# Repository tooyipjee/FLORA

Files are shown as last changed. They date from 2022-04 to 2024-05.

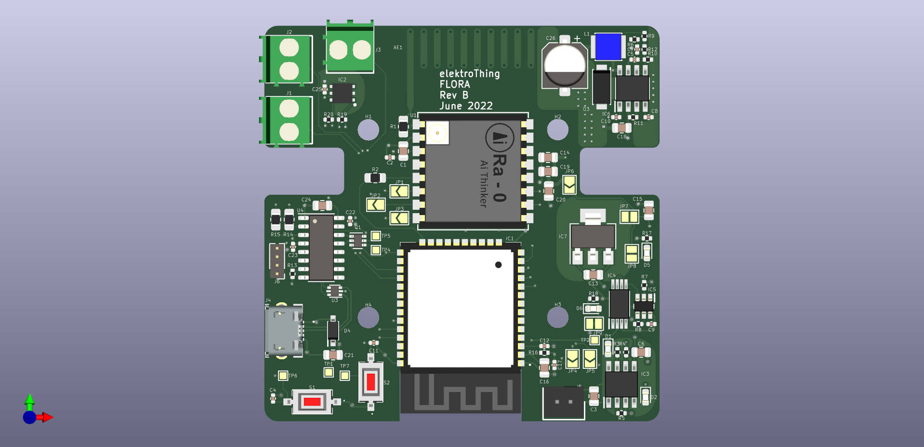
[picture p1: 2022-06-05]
images/flora.png

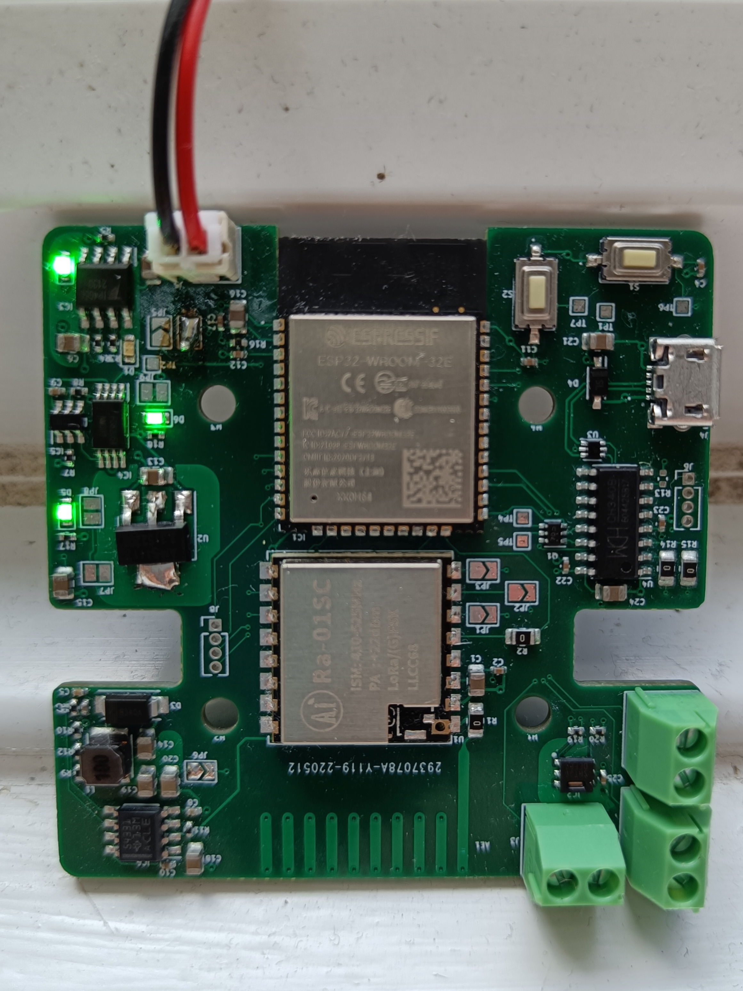
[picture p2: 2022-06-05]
images/IMG20220602151857.jpg

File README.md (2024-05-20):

FLORA: The Smart Garden Weather Station and Soil Moisture Monitor

In 2022, Europe faced its worst drought in over four decades. This marked a significant turning point for sustainable gardening practices across the continent. Amidst this crisis, there is an emerging solution that empowers communities to be more resilient and adaptive to extreme climates: FLORA - A Smart Garden Weather Station with Soil Moisture Monitoring.

The Need for Water-Efficient Practices in Europe's Gardens, Allotments, and Small Farms

The current climate crisis has made it imperative to rethink our approach towards water management and conservation. With the recent drought conditions across Europe, there is an urgent need to implement sustainable practices that can ensure a reliable food supply while conserving precious resources. The project at hand seeks to address this by creating smarter gardens and farms that are efficient in their use of water, thereby mitigating the risks associated with climate change-induced adversities.

Introducing FLORA: A Proof of Concept for Sustainable Gardening

FLORA is an innovative prototyping platform designed to enhance garden and farm productivity while promoting water conservation and sustainability. Built around a low-cost ESP32 SoC, it supports WiFi, BLE, and LoRa connectivity for efficient communication with other smart devices on the same network frequency band up to 3 km away.
e

The platform includes an ambient sensor and various inputs for integrating soil moisture sensors, providing a comprehensive view of environmental factors that influence plant growth. The goal is not just about making gardens more efficient; it's also about bringing communities back in control of their food production systems by making gardening processes rewarding and as effortless as possible.

What Makes FLORA Unique?

Long Range Communication: With the LoRa module, FLORA offers long-range communication up to approximately 2 miles/3 km. This feature is particularly beneficial for expansive gardens or allotments that require monitoring over larger areas without compromising on connectivity.

Soil Moisture Sensor Integration: The companion soil moisture sensor, based on capacitive sensing technology and insulated to prevent corrosion, provides real-time data about the water content in the top layer of the soil. This information is essential for optimizing irrigation practices and avoiding unnecessary water wastage.

Solar Power: FLORA runs on a solar panel powered by coin cell batteries, ensuring it operates sustainably without relying on conventional energy sources.

Vinduino Project Inspiration

The inspiration behind the design of FLORA comes from Reinier van der Lee's project, Vinduino, which showcases how simple electronics sensors can significantly reduce water usage in agriculture by up to 25%. The underlying principles and technologies have been adapted for use in gardening applications.

Building on Plant-Bot Project Experience

Reinier's experience with the Plant-Bot project laid a solid foundation for designing FLORA, allowing it to evolve into an outdoor-focused system that caters specifically to multiple plants and gardens.

Key Features of FLORA:

Compatibility with WiFi, BLE, and LoRa connectivity for seamless communication

Temperature accuracy within 0.3°C and humidity accuracy up to 3% RH using the SHT20 sensor

Capable of integrating various soil moisture sensors with capacitive-based technology

Long-range communication capabilities, extending FLORA's coverage area significantly

Efficient energy consumption powered by a solar panel and coin cell battery system

User-friendly design that empowers gardeners to take control of their plant care processes

Versatility in customization and integration with other smart devices within the same network frequency band

Specification Details:

Microcontroller: ESP32-WROOM-32E

WiFi Support: 802.11b/g/n standard

Bluetooth Capabilities: BLE 4.2 version

Flash Memory: 8MB capacity for firmware storage and execution

Programming Interface: USB over UART (CP2102) for direct programming and control

Environment Sensor: Incorporates the SHT20 sensor to measure temperature and humidity accurately

Soil Moisture Measurement: Utilizes capacitive sensing technology for reliable soil moisture readings

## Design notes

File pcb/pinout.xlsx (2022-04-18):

GPIO | Function 1 | System 1 | Function 2 | System 2
0 | Strapping | MCU
2 | TXEN | LoRa
4
5 | nNSS | LoRa
12 | TDI | SWD
13 | TCK | SWD
14 | nRESET | LoRa | TMS | SWD
15 | TDO | SWD
16 | SDA | I2C
17 | SCL | I2C
18 | SCK | LoRa
19 | MISO | LoRa
21 | BUSY | LoRa
22 | RXED | LoRa
23 | MOSI | LoRa
25 | DIO1 | LoRa
26 | DIO2 | LoRa
27 | DIO3 | LoRa
32
33 | SOIL_1 | SOIL
34 | SOIL_2 | SOIL
35 | SOIL_3 | SOIL

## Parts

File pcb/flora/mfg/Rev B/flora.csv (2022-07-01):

Comment | Designator | Footprint | LCSC
Antenna | AE1 | RF_Antenna:Texas_SWRA416_868MHz_915MHz
Battery_Cell | BT1 | BatteryHolders:BS-24-B4AK014
10u | C1,C3,C6,C13,C14,C15,C21,C24 | Capacitor_SMD:C_0805_2012Metric | C15850
22u | C16,C18,C19,C20 | Capacitor_SMD:C_0805_2012Metric | C602037
100n | C2,C4,C9,C10,C11,C12,C17,C22,C23,C25 | Capacitor_SMD:C_0402_1005Metric | C307331
220uF_E_LV | C26 | Capacitor_SMD:CP_Elec_6.3x5.4 | C3345
4.7n | C5 | Capacitor_SMD:C_0402_1005Metric | C1538
8.2n | C7,C8 | Capacitor_SMD:C_0402_1005Metric | C107032
Green_0603 | D1,D2,D5,D6 | LED_SMD:LED_0603_1608Metric | C72043
B340A-13-F | D3 | DIOM5226X240N | C64982
1N5819HWQ-7-F | D4 | SOD3716X145N | C2905649
MountingHole | H1,H2,H3,H4 | personal:MountingHole_3.2mm_M3_Small
ESP32-WROOM-32E(8MB) | IC1 | ESP32WROOM32E8MB | C701342
SHT20 | IC2 | SON100P300X300X110-7N
TP4056X | IC3 | SOIC127P600X175-9N | C16581
FS8205A | IC4 | SOP65P640X120-8N | C16052
DW01+G | IC5 | SamacSys_Parts:SOT95P280X145-6N | C14213
TPS54331DR | IC6 | SOIC127P600X175-8N
AMS1117-3.3 | IC7 | Package_TO_SOT_SMD:SOT-223-3_TabPin2 | C6186
KF350-3.5-2P | J1,J2,J3 | KF350352P | C474892
10118193-0001LF | J4 | 101181930001LF
PH-2V | J5 | SHDR2W52P0X200_1X2_600X460X630P | C146082
Conn_01x04 | J6 | Connector_PinHeader_1.27mm:PinHeader_1x04_P1.27mm_Vertical
SB_NO | JP1,JP2,JP3,JP4,JP5,JP6 | Jumper:SolderJumper-2_P1.3mm_Open_TrianglePad1.0x1.5mm
SB_NC | JP7,JP8,JP9 | Jumper:SolderJumper-2_P1.3mm_Bridged_Pad1.0x1.5mm
10uH | L1 | SamacSys_Parts:INDPM4040X300N | C38117
MUN5214DW1T1G | Q1 | Package_TO_SOT_SMD:SOT-363_SC-70-6 | C94403
0 | R1,R2,R14,R15 | Resistor_SMD:R_0805_2012Metric_Pad1.20x1.40mm_HandSolder | C17477
3.3k | R10 | Resistor_SMD:R_0402_1005Metric | C25890
220 | R12 | Resistor_SMD:R_0402_1005Metric | C25091
DNF_0402 | R13 | Resistor_SMD:R_0402_1005Metric
10k | R5,R9,R11,R16,R19,R20 | Resistor_SMD:R_0402_1005Metric | C25744
2.2k | R3,R18 | Resistor_SMD:R_0402_1005Metric | C25879
1k | R4,R6,R7,R17 | Resistor_SMD:R_0402_1005Metric | C11702
100 | R8 | Resistor_SMD:R_0402_1005Metric | C25076
TS-1101-C-W | S1,S2 | TS1101CW | C318938
USB Test Point | TP3 | personal:USB_TestPoint
TestPoint_Alt | TP1,TP2,TP4,TP5,TP6,TP7 | TestPoint:TestPoint_Pad_1.0x1.0mm
Ai-Thinker-Ra-01H | U1 | RF_Module:Ai-Thinker-Ra-01-LoRa | C503593
USBLC6-2P6 | U3 | Package_TO_SOT_SMD:SOT-666 | C2827693
CH340C | U4 | Package_SO:SOIC-16_3.9x9.9mm_P1.27mm | C84681

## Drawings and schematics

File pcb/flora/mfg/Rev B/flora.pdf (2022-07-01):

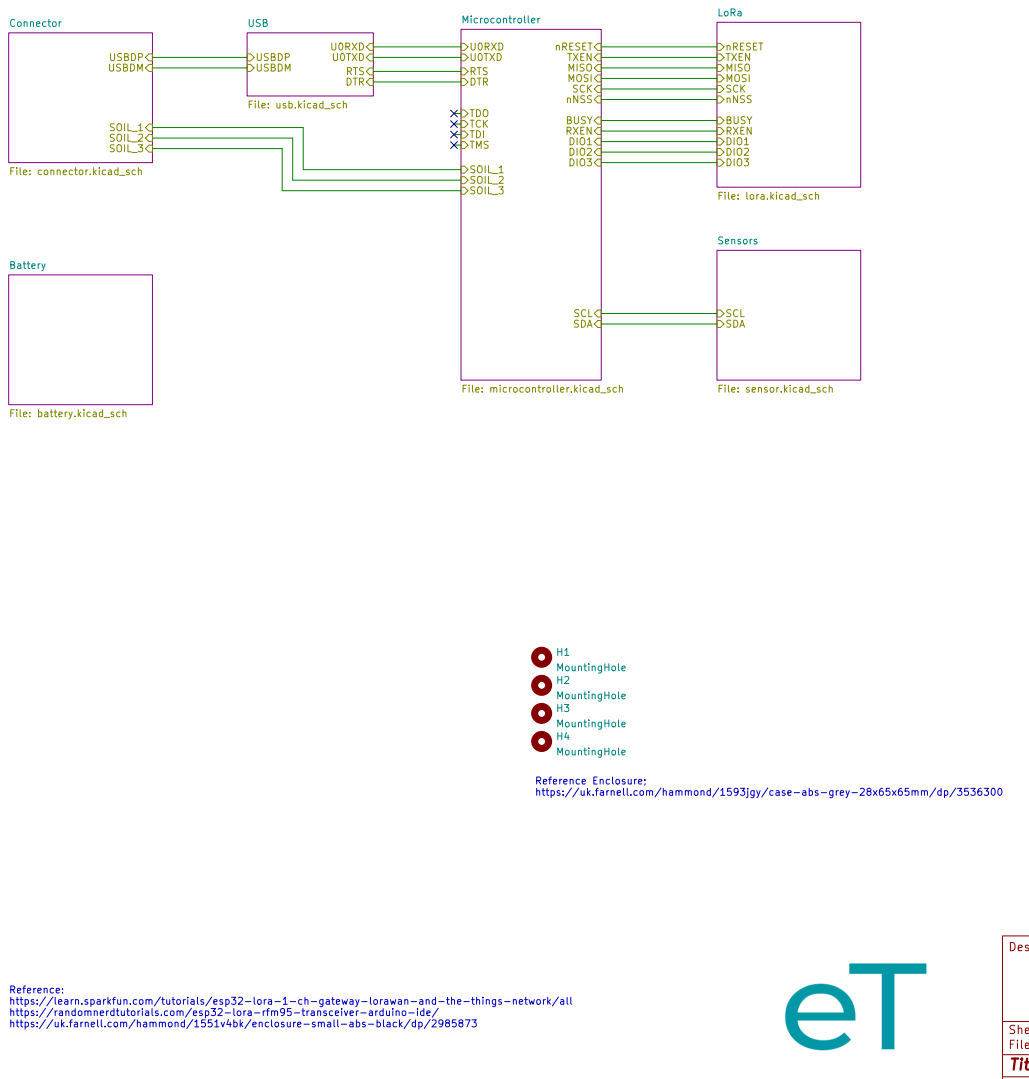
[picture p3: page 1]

LoRa File: lora.kicad_sch SDA
nRESET DIO2 DIO1 DIO3

DIO2 DIO3 DIO1 Microcontroller File: microcontroller.kicad_sch H4MountingHole H1MountingHole H2MountingHole H3MountingHole Reference: https://learn.sparkfun.com/tutorials/esp32-lora-1-ch-gateway-lorawan-and-the-things-network/all

RTS USB
TXEN MISO MOSI SCL SDA U0RXD
U0TXD
TDI TMS RTS DTR

SCL Sensors File: sensor.kicad_sch SOIL_3 SOIL_2 SOIL_1 USBDP USBDM

File: flora.kicad_sch Sheet: / Designed by elektroThing

https://randomnerdtutorials.com/esp32-lora-rfm95-transceiver-arduino-ide/

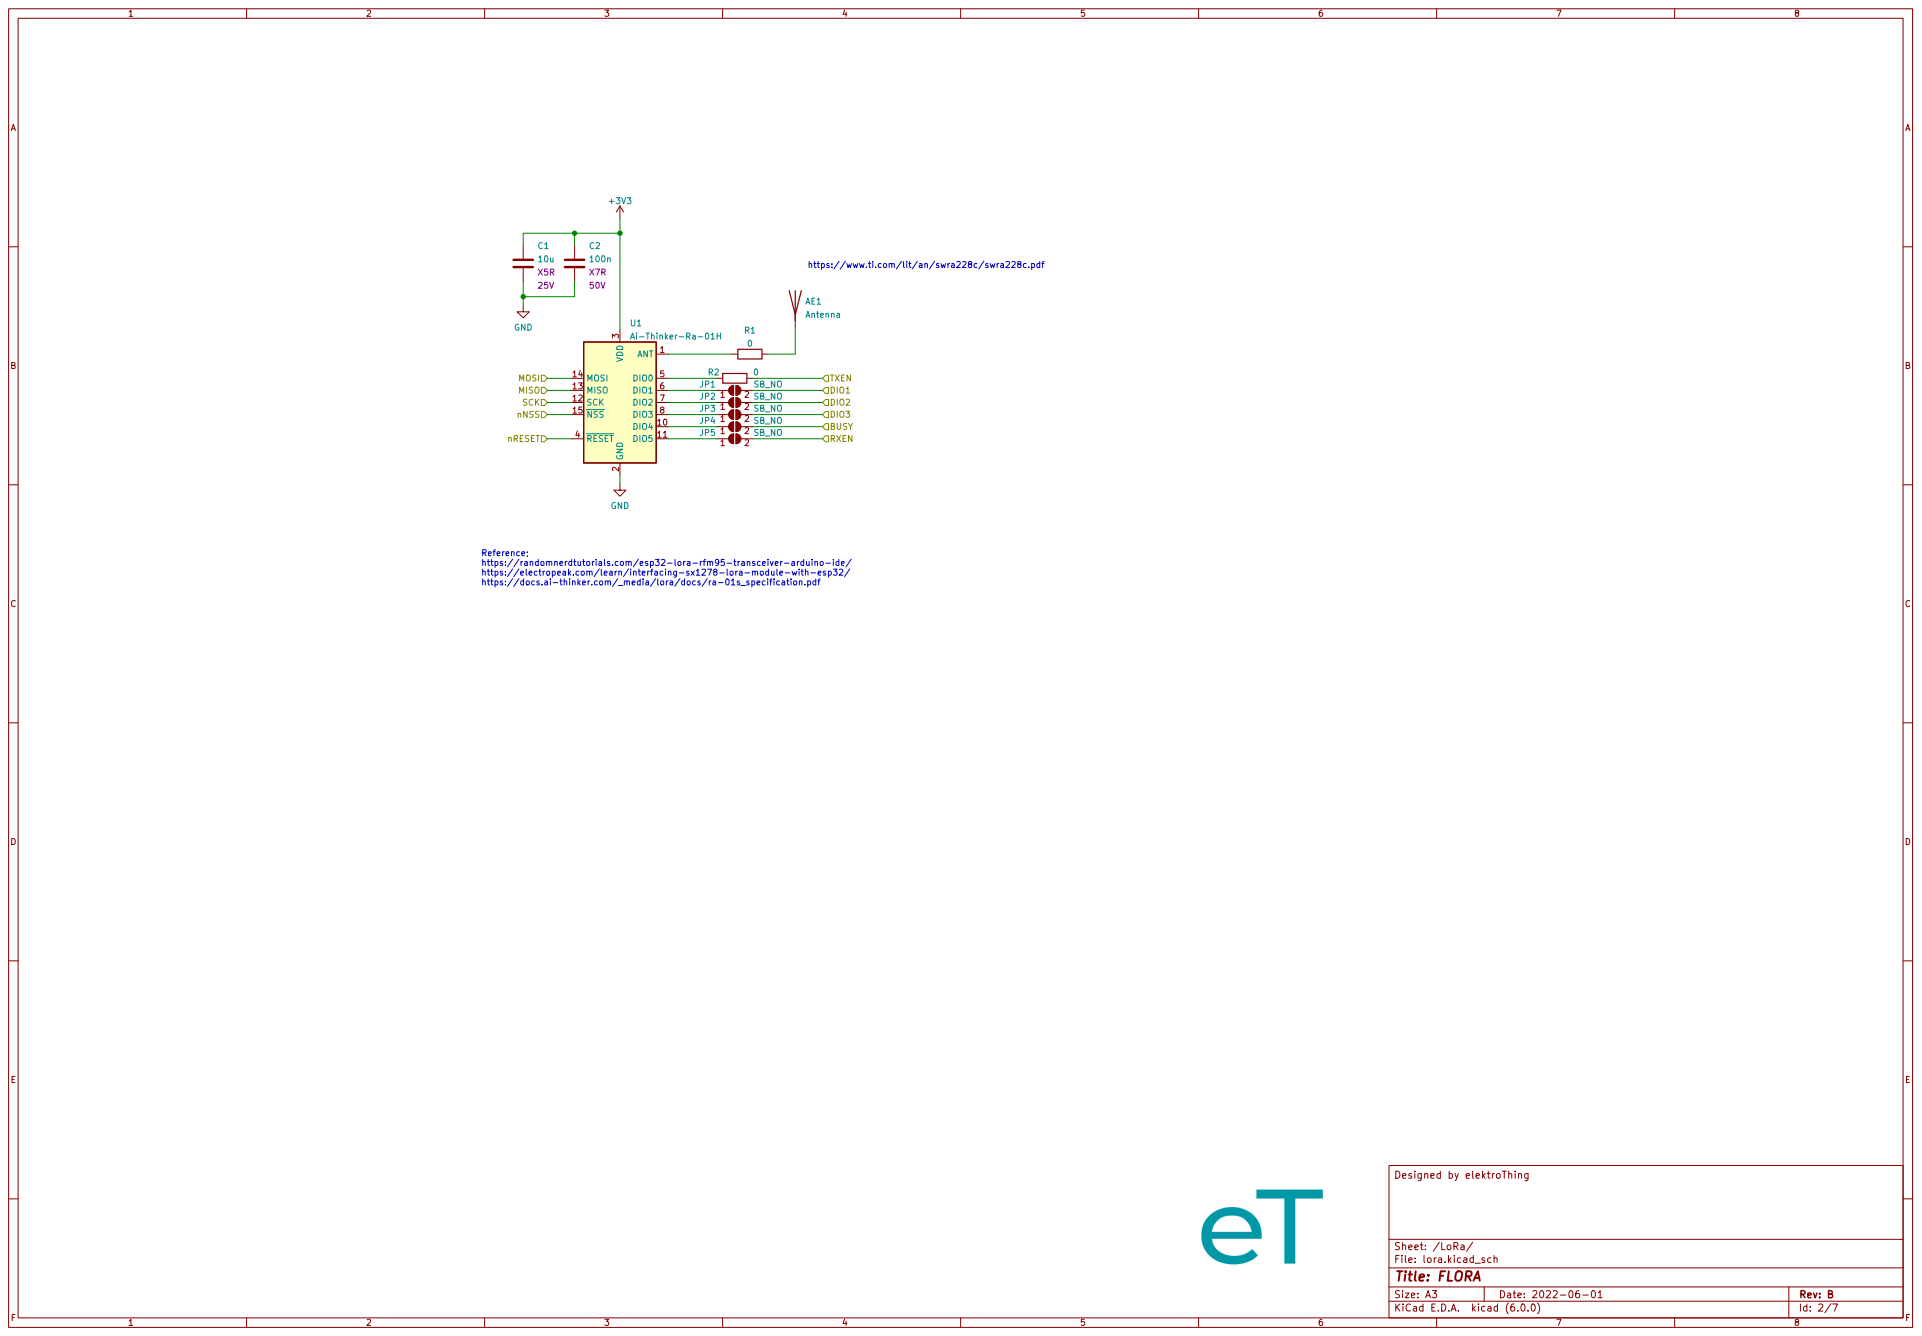
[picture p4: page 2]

https://www.ti.com/lit/an/swra228c/swra228c.pdf Reference; https://randomnerdtutorials.com/esp32-lora-rfm95-transceiver-arduino-ide/

3 ~{RESET} 4 DIO0 5 DIO1 6 DIO2 7 DIO3 8 U1Ai-Thinker-Ra-01H GND

https://electropeak.com/learn/interfacing-sx1278-lora-module-with-esp32/
https://docs.ai-thinker.com/_media/lora/docs/ra-01s_specification.pdf

File: lora.kicad_sch Sheet: /LoRa/ Designed by elektroThing

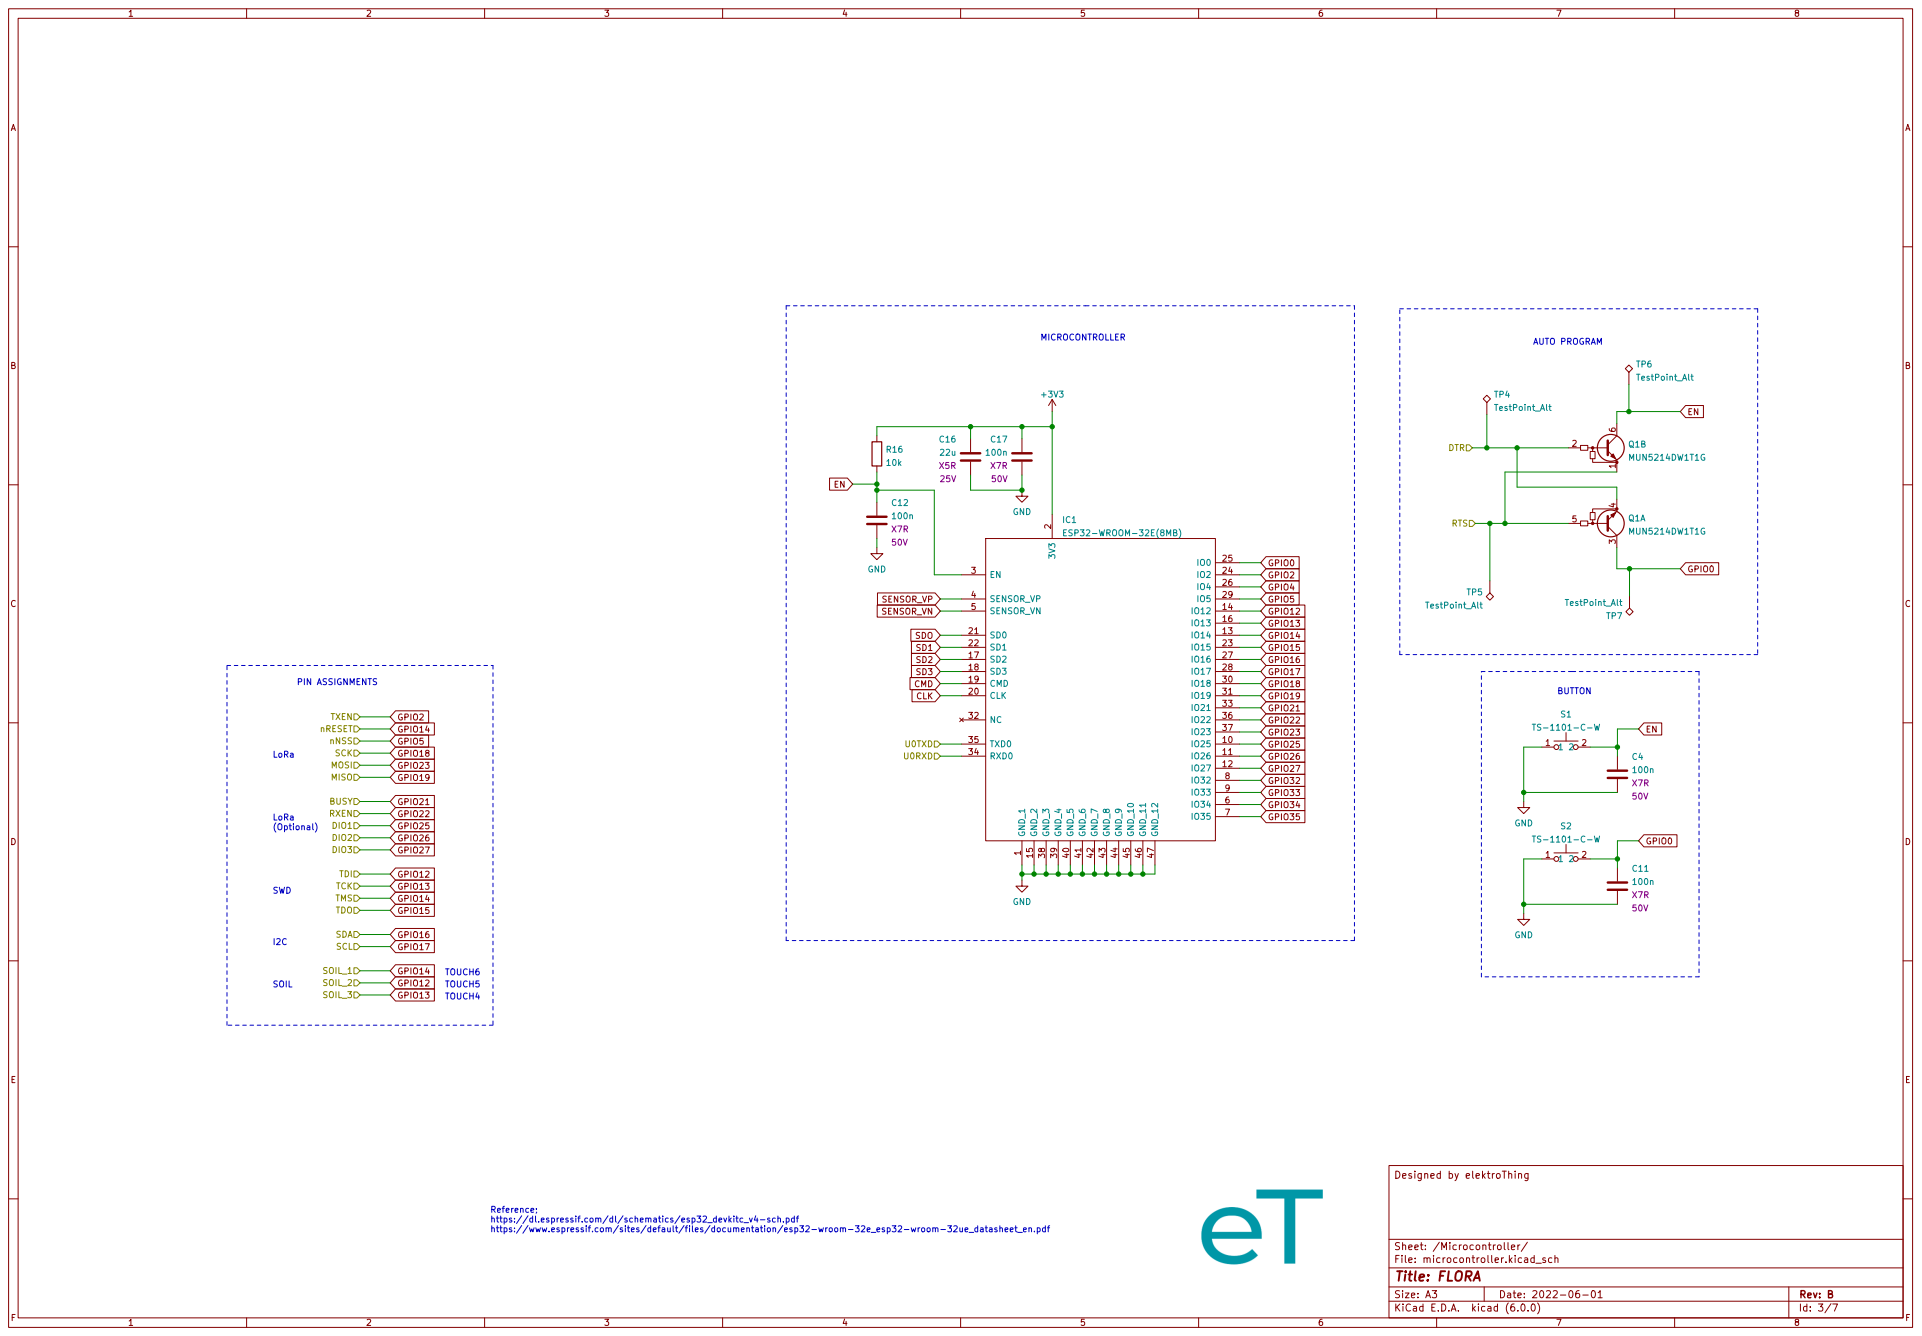
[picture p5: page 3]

File: microcontroller.kicad_sch Sheet: /Microcontroller/ Designed by elektroThing GND

https://www.espressif.com/sites/default/files/documentation/esp32-wroom-32e_esp32-wroom-32ue_datasheet_en.pdf SWD

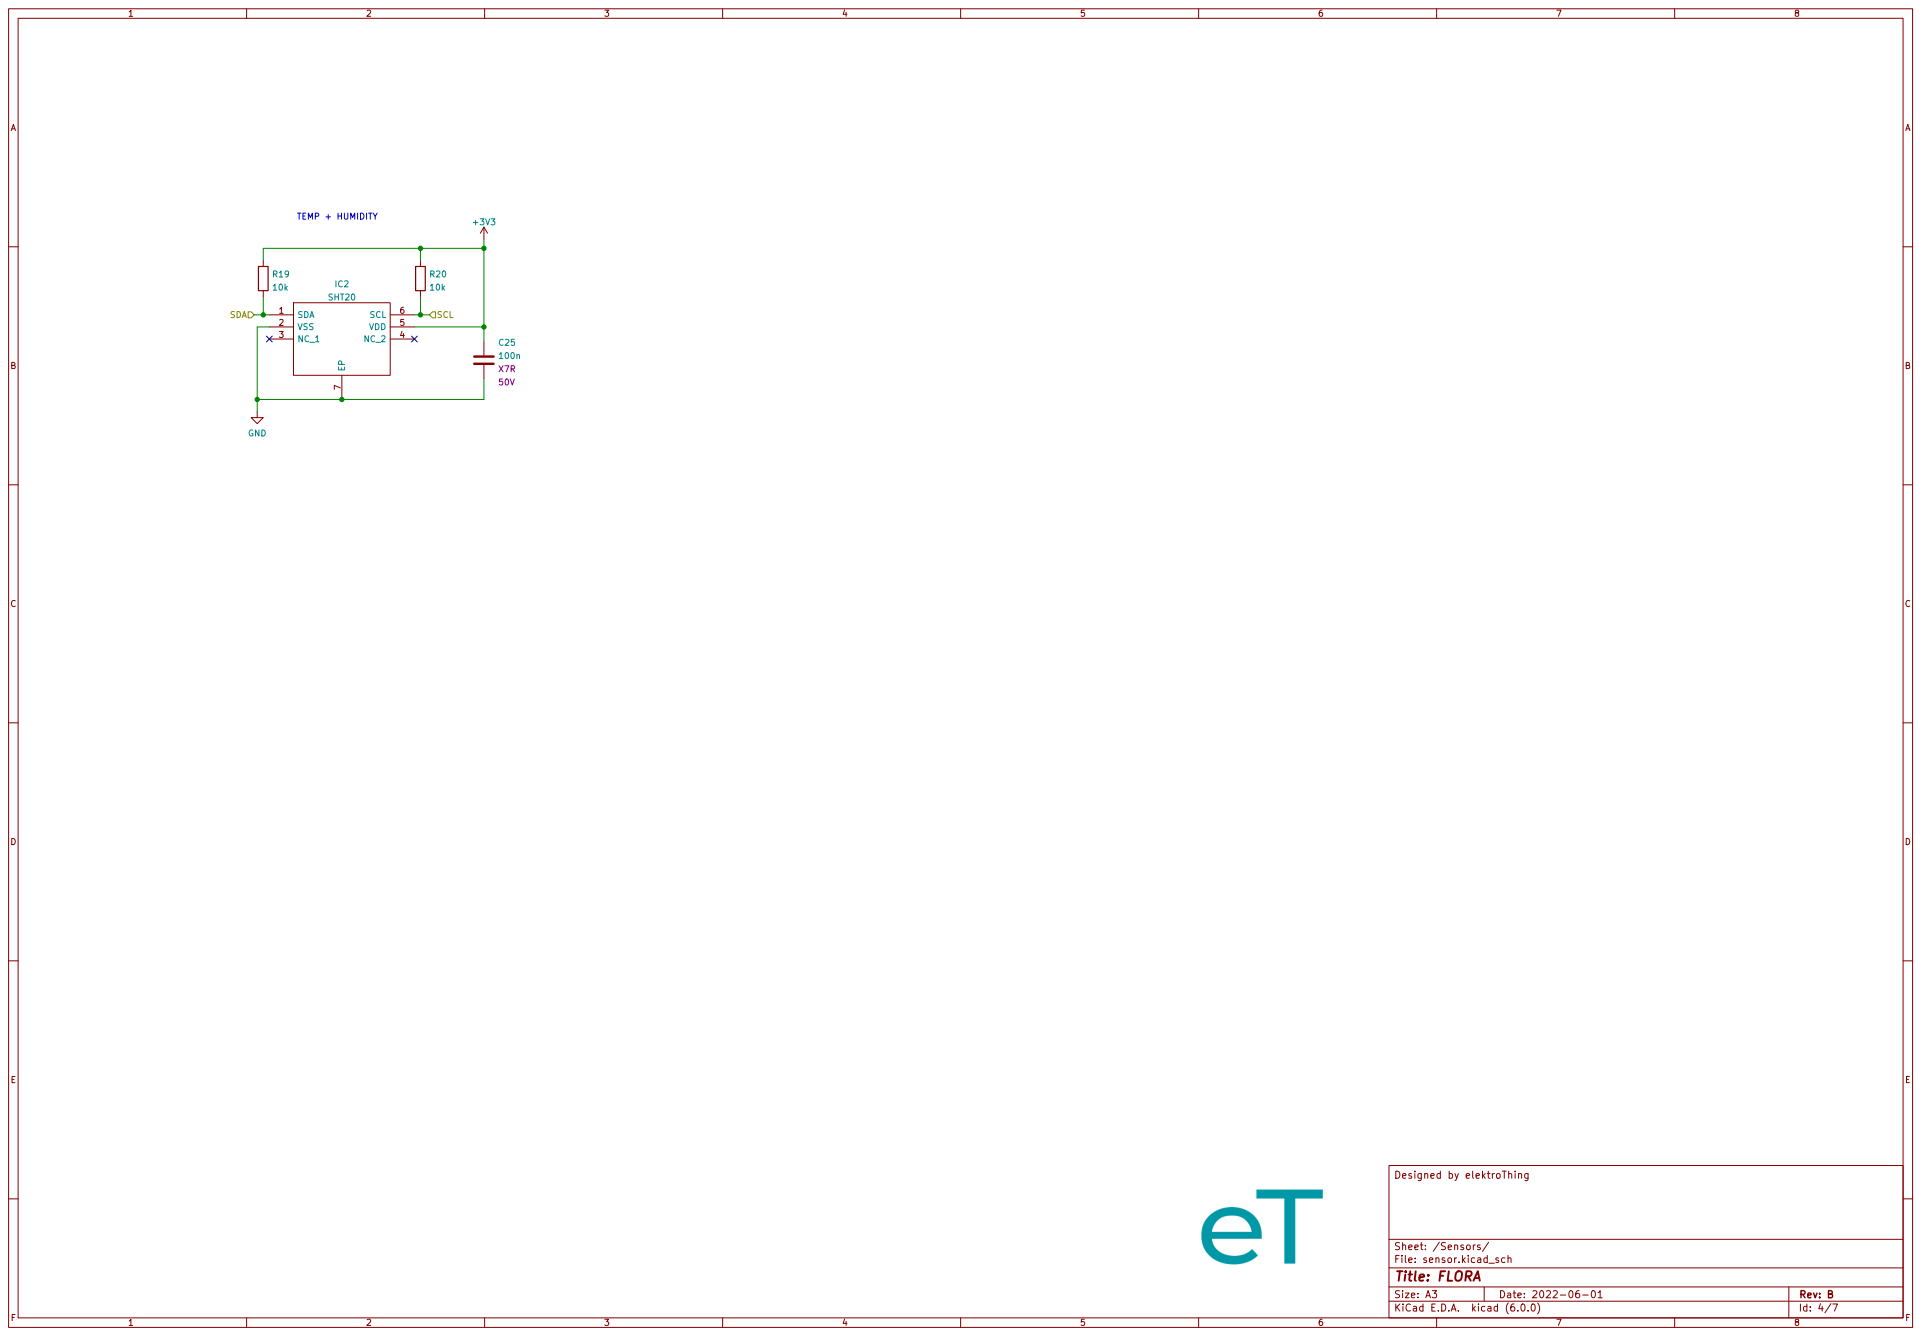
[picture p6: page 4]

File: sensor.kicad_sch Sheet: /Sensors/ Designed by elektroThing

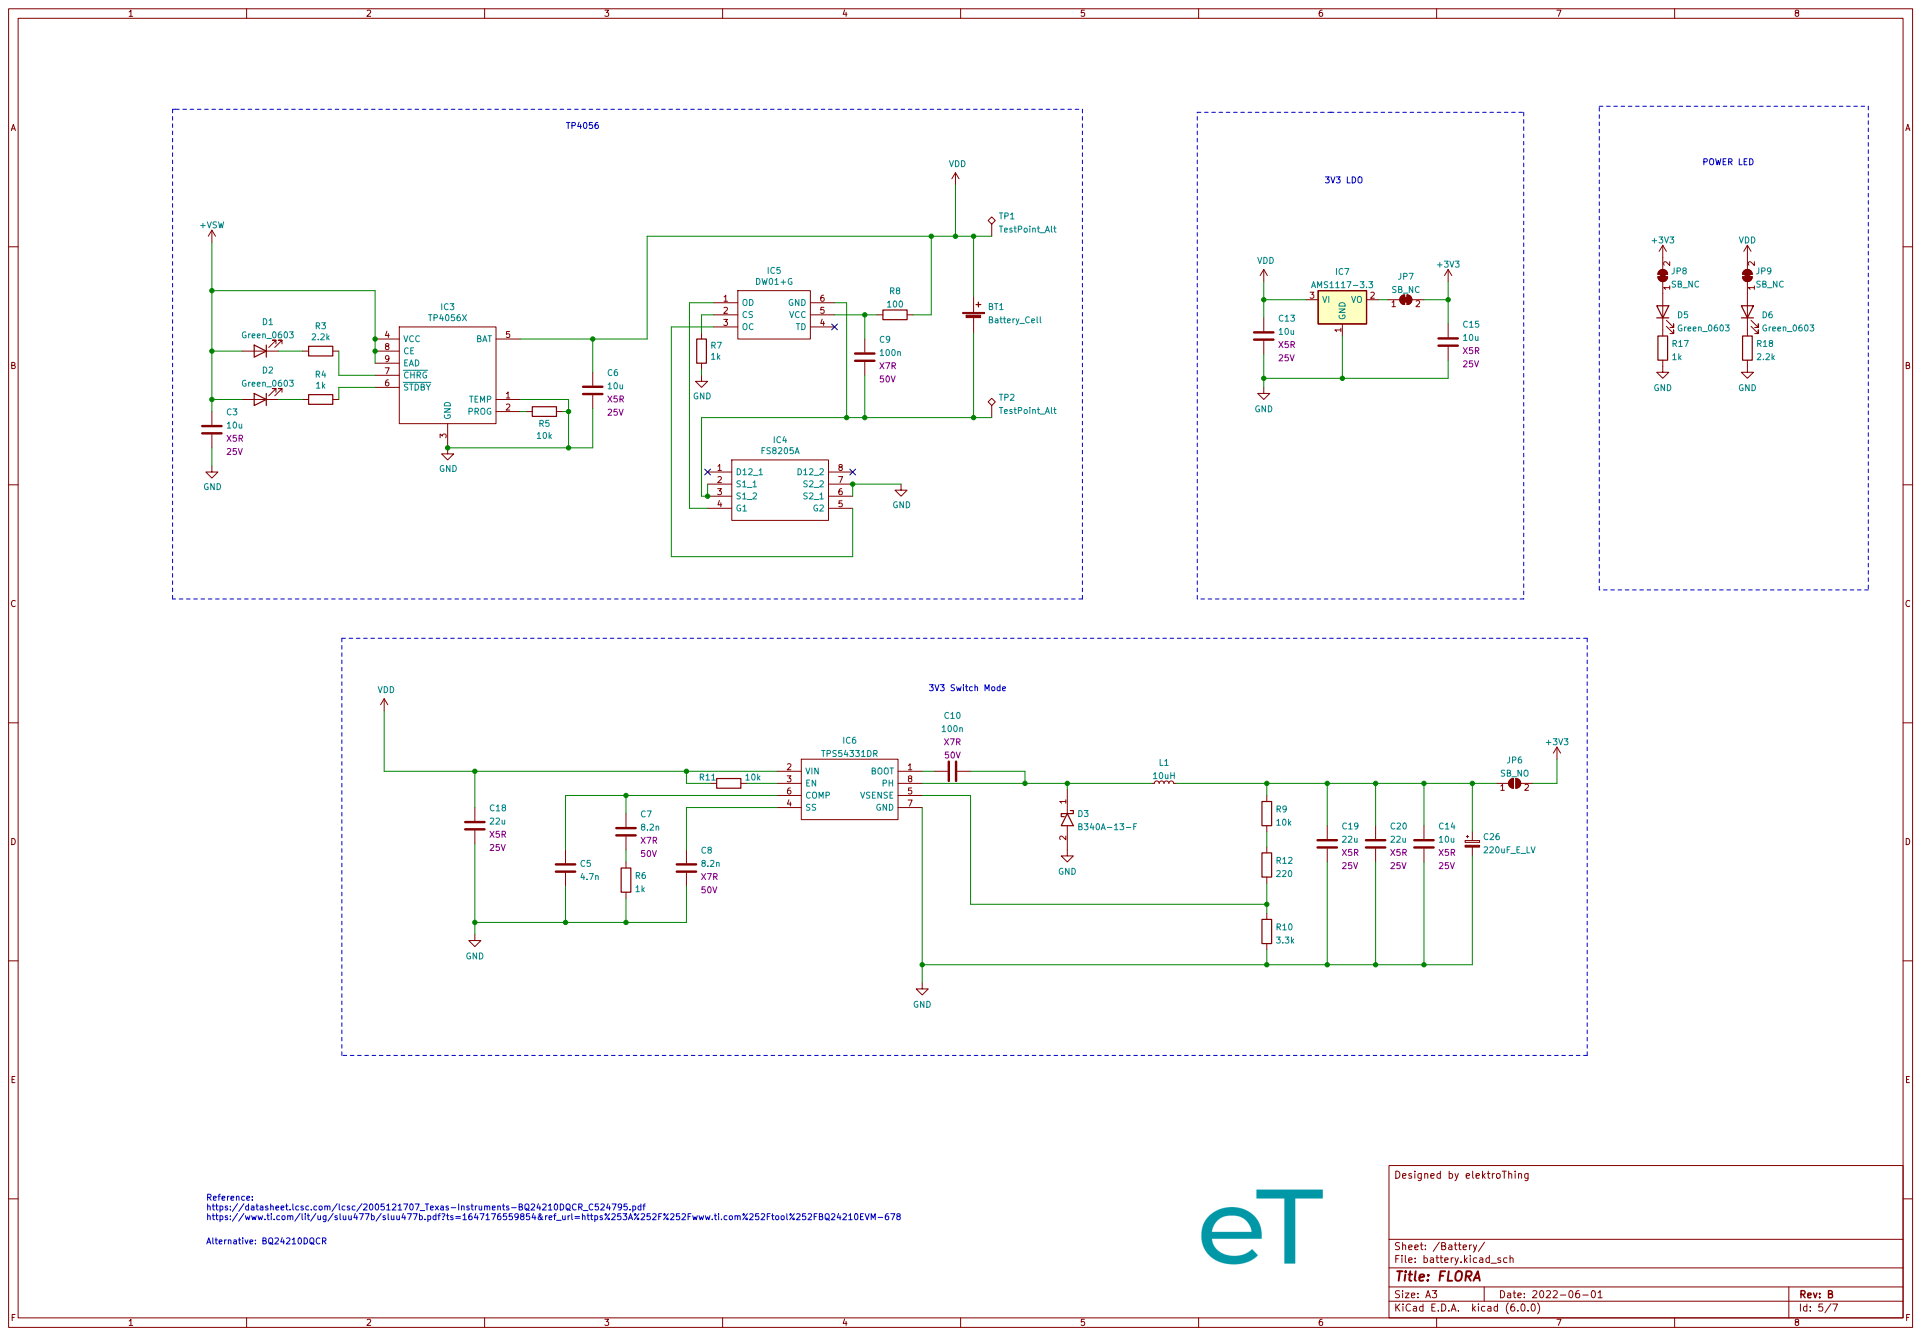
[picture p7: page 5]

3 VCC 4 BAT 5 ~{STDBY} 6 ~{CHRG} 7 CE 8 EAD 9

GND GND

3V3 Switch Mode Reference: https://datasheet.lcsc.com/lcsc/2005121707_Texas-Instruments-BQ24210DQCR_C524795.pdf

https://www.ti.com/lit/ug/sluu477b/sluu477b.pdf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 Alternative: BQ24210DQCR

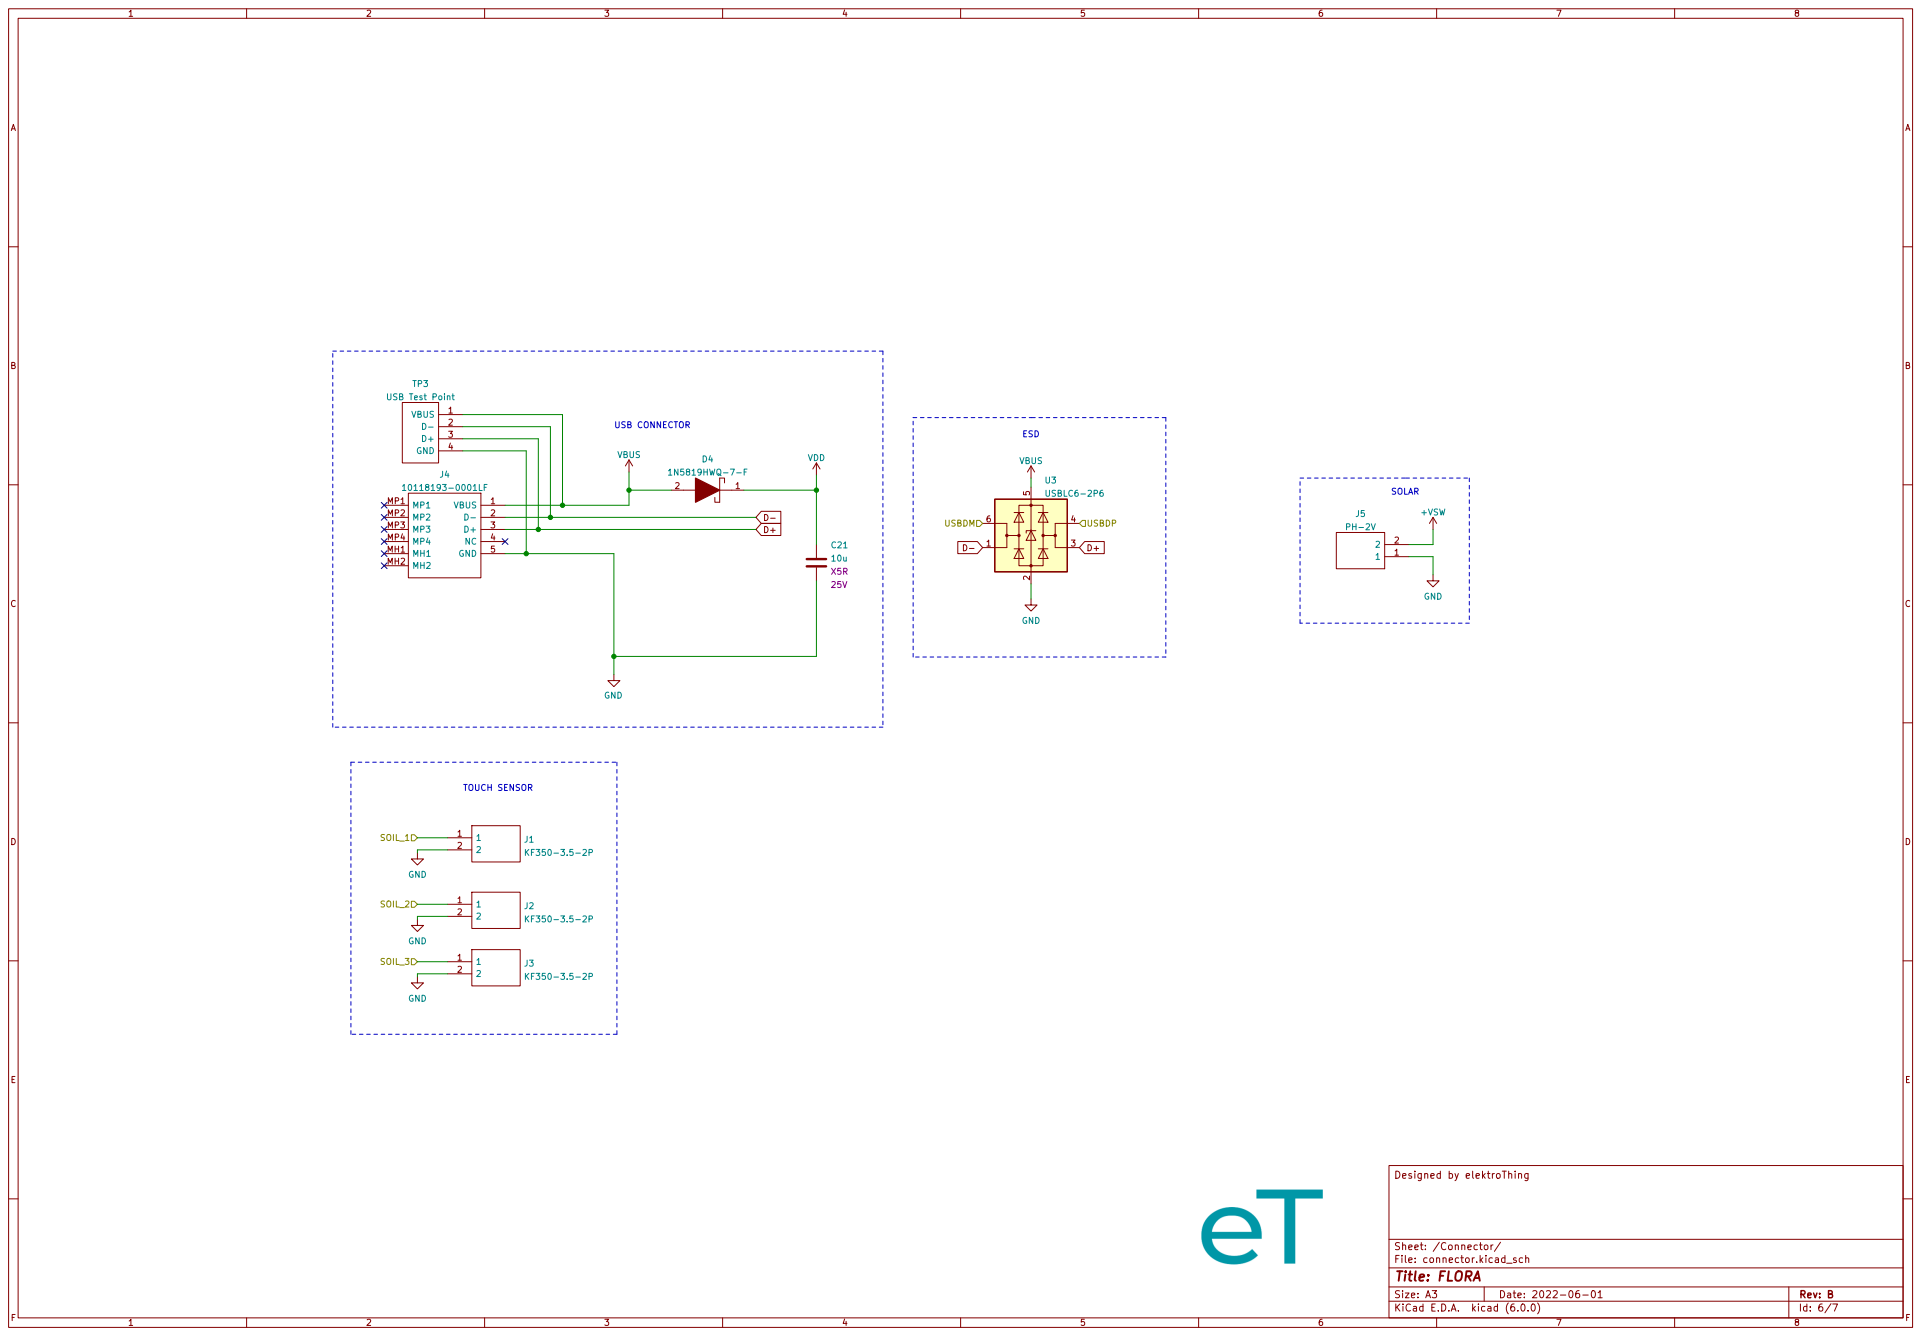
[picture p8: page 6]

File: connector.kicad_sch Sheet: /Connector/ Designed by elektroThing

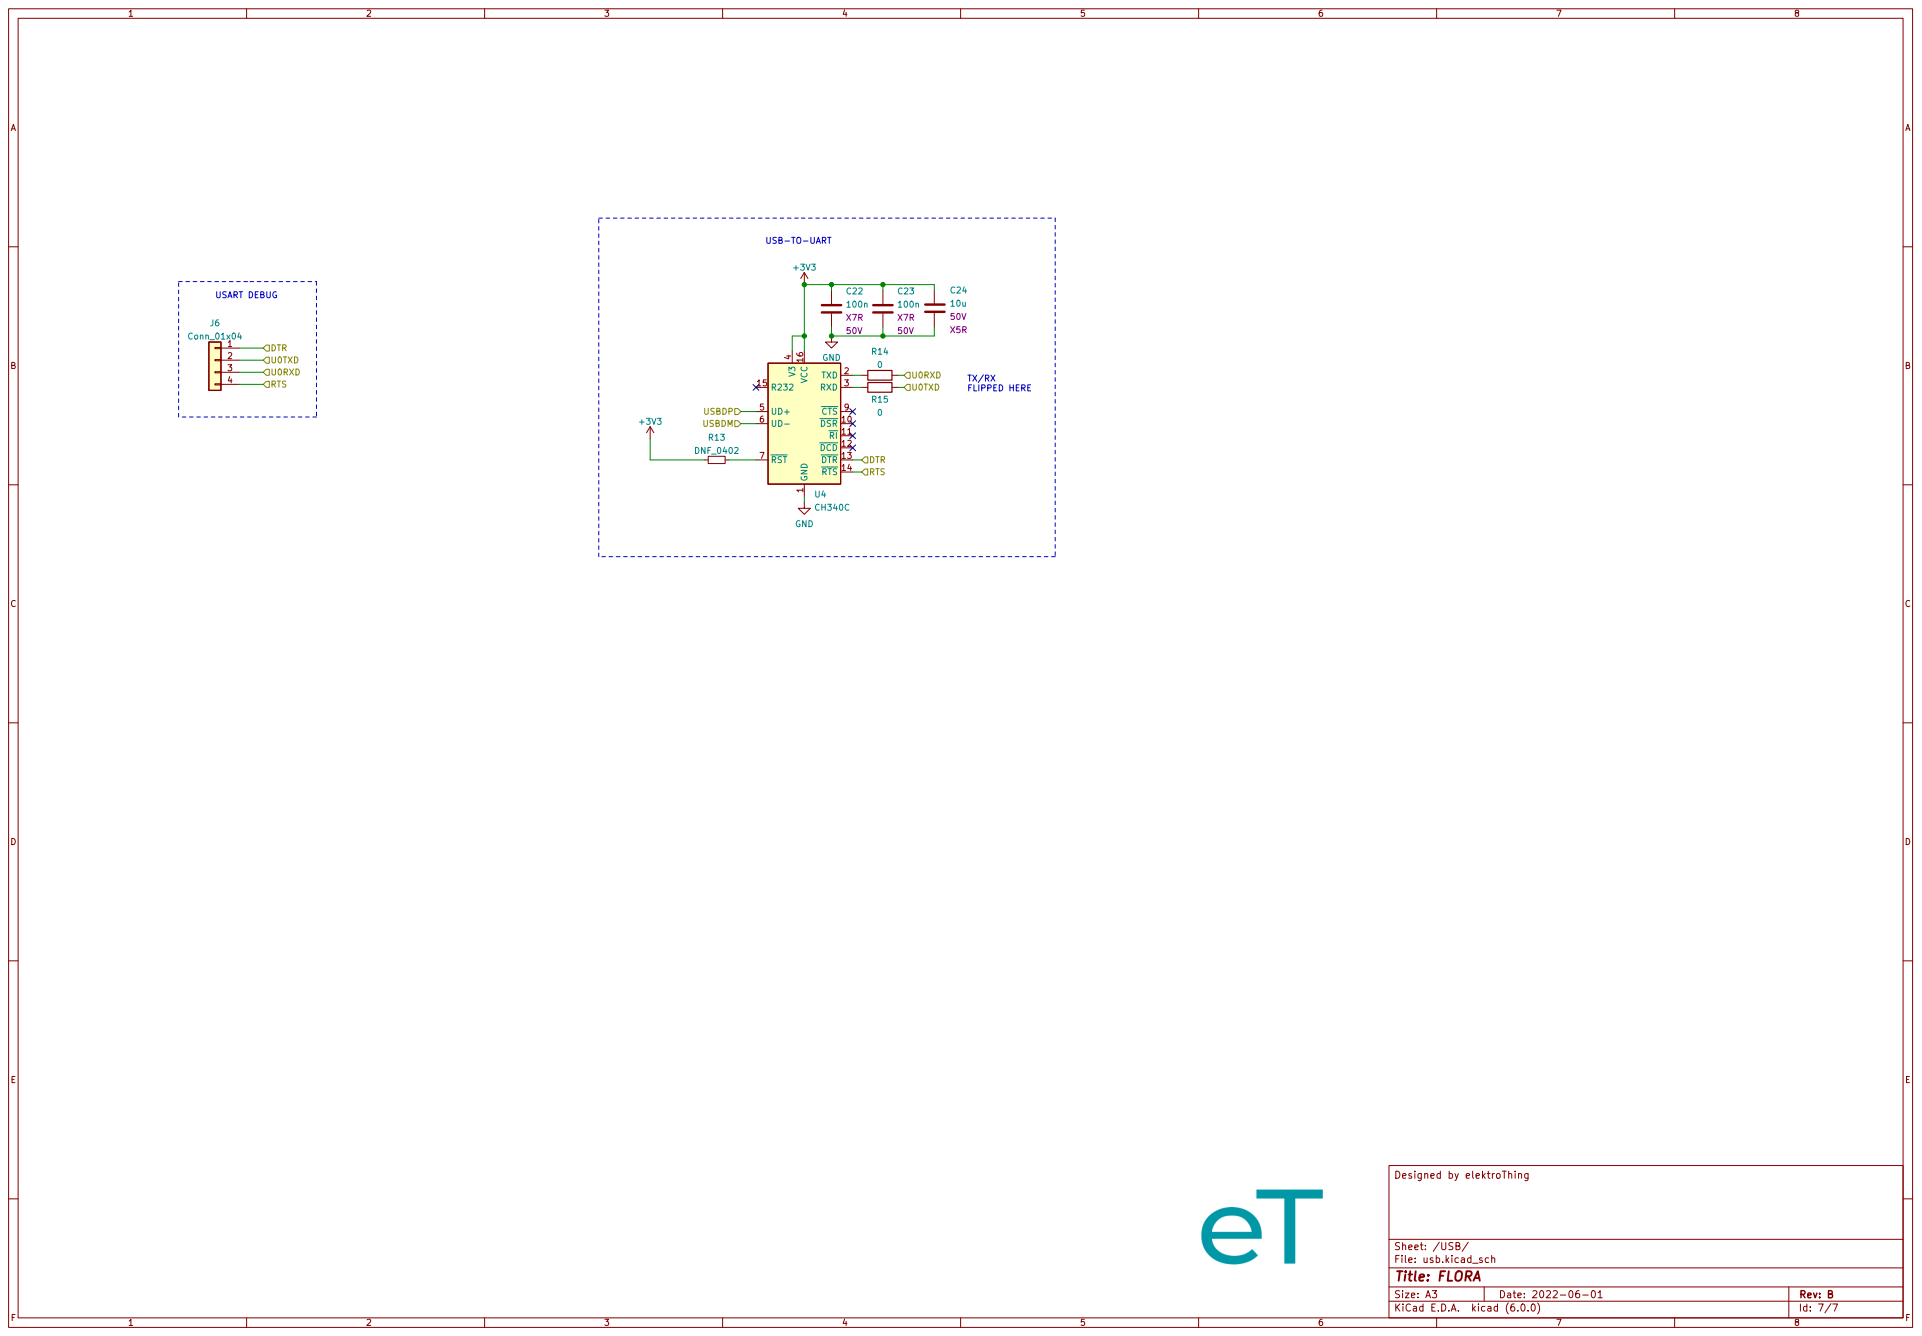
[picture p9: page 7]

USB-TO-UART USART DEBUG

1 ~{DSR}10 ~{RI}11 ~{DCD}12 ~{DTR}13 ~{RTS}14 R232 15 VCC 16 TXD 2 RXD 3 V3

4 UD+ 5 UD- 6 ~{RST} 7 ~{CTS} 9 U4CH340C

TX/RX FLIPPED HERE

File: usb.kicad_sch Sheet: /USB/ Designed by elektroThing

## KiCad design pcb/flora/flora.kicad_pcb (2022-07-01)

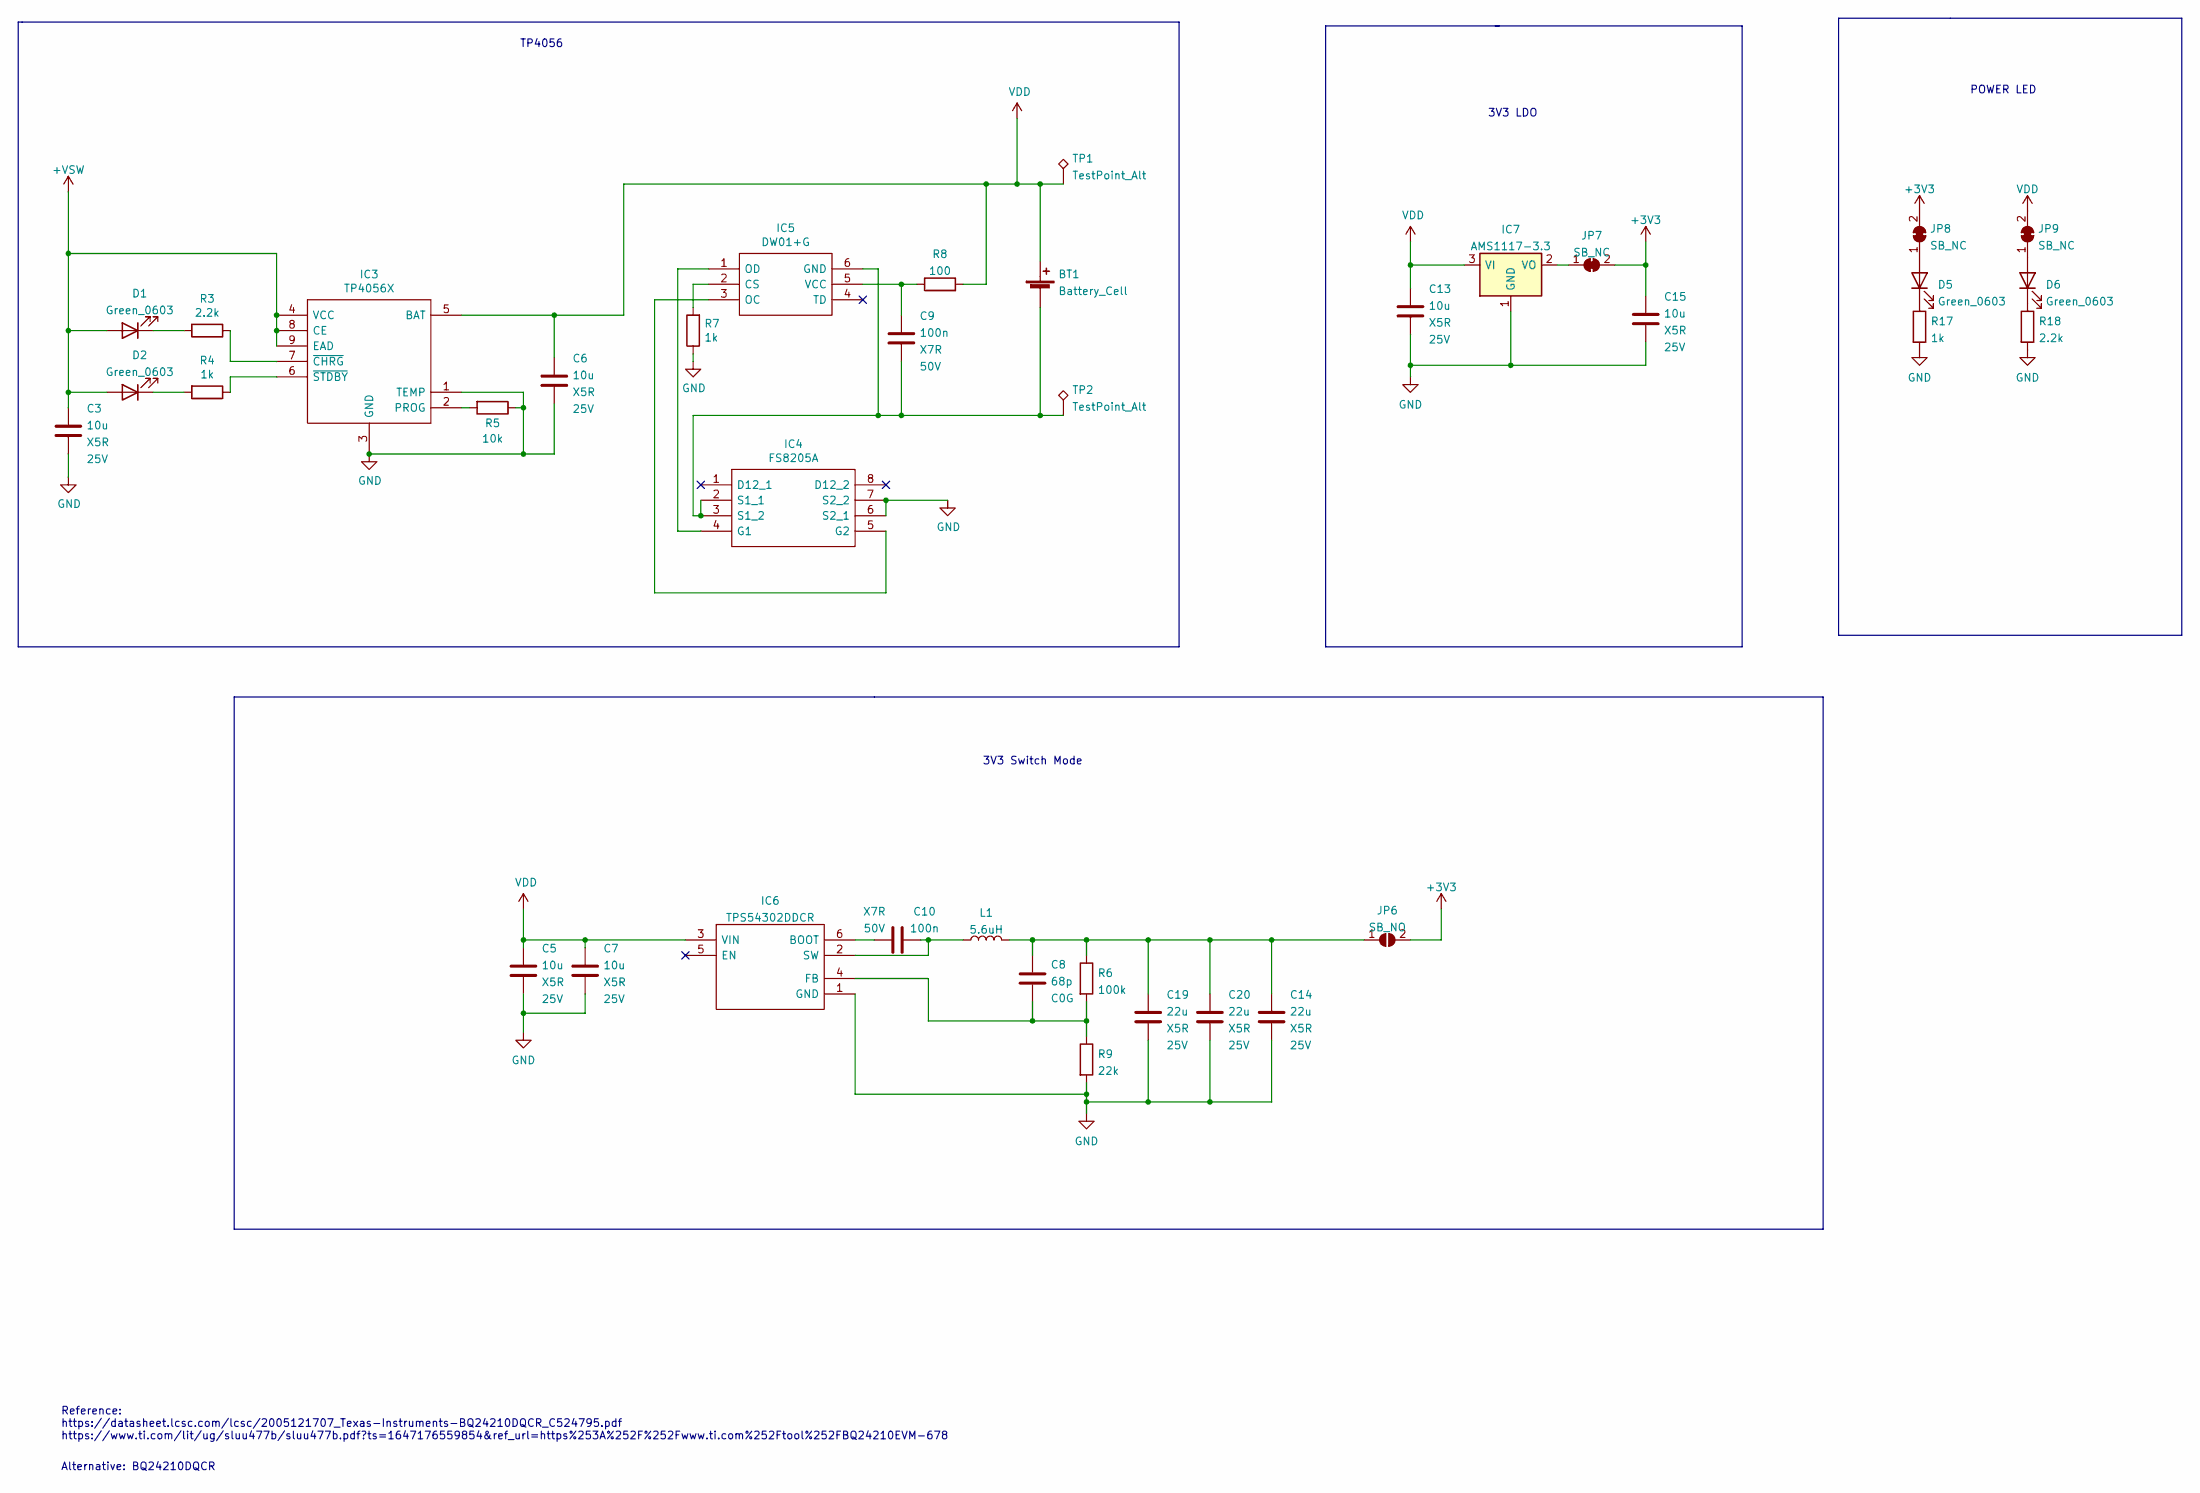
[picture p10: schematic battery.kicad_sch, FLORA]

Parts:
BT1: Battery_Cell; BS-24-B4AK014
C3, C5, C6, C7, C13, C15: 10u; C_0805_2012Metric; Voltage 25V; LCSC C15850
C8: 68p; C_0402_1005Metric; Rating 50V; LCSC C14441
C9, C10: 100n; C_0402_1005Metric; Voltage 50V; LCSC C307331
C14, C19, C20: 22u; C_0805_2012Metric; Voltage 25V; LCSC C602037
D1, D2, D5, D6: Green_0603; LED_0603_1608Metric; LCSC C72043
IC3: TP4056X; SOIC127P600X175-9N; Manufacturer_Part_Number TP4056X; LCSC C16581
IC4: FS8205A; SOP65P640X120-8N; Manufacturer_Part_Number FS8205A; LCSC C16052
IC5: DW01+G; SOT95P280X145-6N; Manufacturer_Part_Number DW01+G; LCSC C14213
IC6: TPS54302DDCR; SOT95P280X110-6N; Manufacturer_Part_Number TPS54302DDCR; Mouser Part Number 595-TPS54302DDCR
IC7: AMS1117-3.3; SOT-223-3_TabPin2; Manufacturer_Part_Number AMS1117-3.3; LCSC C6186
JP6: SB_NO; SolderJumper-2_P1.3mm_Open_TrianglePad1.0x1.5mm
JP7, JP8, JP9: SB_NC; SolderJumper-2_P1.3mm_Bridged_Pad1.0x1.5mm
L1: 5.6uH; INDPM4040X300N; LCSC C167783
R3, R18: 2.2k; R_0402_1005Metric; LCSC C25879
R4, R7, R17: 1k; R_0402_1005Metric; LCSC C11702
R5: 10k; R_0402_1005Metric; LCSC C25744
R6: 100k; R_0402_1005Metric; LCSC C25741
R8: 100; R_0402_1005Metric; LCSC C25076
R9: 22k; R_0402_1005Metric; LCSC C25768
TP1, TP2: TestPoint_Alt; TestPoint_Pad_1.0x1.0mm

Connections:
+3V3: C15.1, JP6.2 (B), JP7.2 (B), JP8.2 (B); also elsewhere on the board
+VSW: C3.1, D1.2 (A), D2.2 (A), IC3.4 (VCC), IC3.8 (CE), IC3.9 (EAD); also elsewhere on the board
GND: C3.2, C5.2, C6.2, C7.2, C13.2, C14.2, C15.2, C19.2, C20.2, IC3.1 (TEMP), IC3.3 (GND), IC4.6 (S2_1), IC4.7 (S2_2), IC6.1 (GND), IC7.1 (GND), R5.1, R7.1, R9.2, R17.2, R18.2; also elsewhere on the board
unnamed: BT1.2 (-), C9.2, IC4.2 (S1_1), IC4.3 (S1_2), IC5.6 (GND), TP2.1
unnamed: C8.2, IC6.4 (FB), R6.2, R9.1
unnamed: C9.1, IC5.5 (VCC), R8.1
unnamed: C10.1, IC6.6 (BOOT)
unnamed: C10.2, IC6.2 (SW), L1.1
unnamed: C8.1, C14.1, C19.1, C20.1, JP6.1 (A), L1.2, R6.1
unnamed: D1.1 (K), R3.2
unnamed: D2.1 (K), R4.2
unnamed: D5.1 (K), R17.1
unnamed: D5.2 (A), JP8.1 (A)
unnamed: D6.1 (K), R18.1
unnamed: D6.2 (A), JP9.1 (A)
unnamed: IC3.2 (PROG), R5.2
unnamed: IC3.6 (~STDBY), R4.1
unnamed: IC3.7 (~CHRG), R3.1
unnamed: IC4.4 (G1), IC5.1 (OD)
unnamed: IC4.5 (G2), IC5.3 (OC)
unnamed: IC5.2 (CS), R7.2
unnamed: IC7.2 (VO), JP7.1 (A)
VDD: BT1.1 (+), C5.1, C6.1, C7.1, C13.1, IC3.5 (BAT), IC6.3 (VIN), IC7.3 (VI), JP9.2 (B), R8.2, TP1.1; also elsewhere on the board

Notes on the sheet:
3V3 Switch Mode
Reference: https://datasheet.lcsc.com/lcsc/2005121707_Texas-Instruments-BQ24210DQCR_C524795.pdf https://www.ti.com/lit/ug/sluu477b/sluu477b.pdf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
POWER LED
TP4056
Alternative: BQ24210DQCR
3V3 LDO

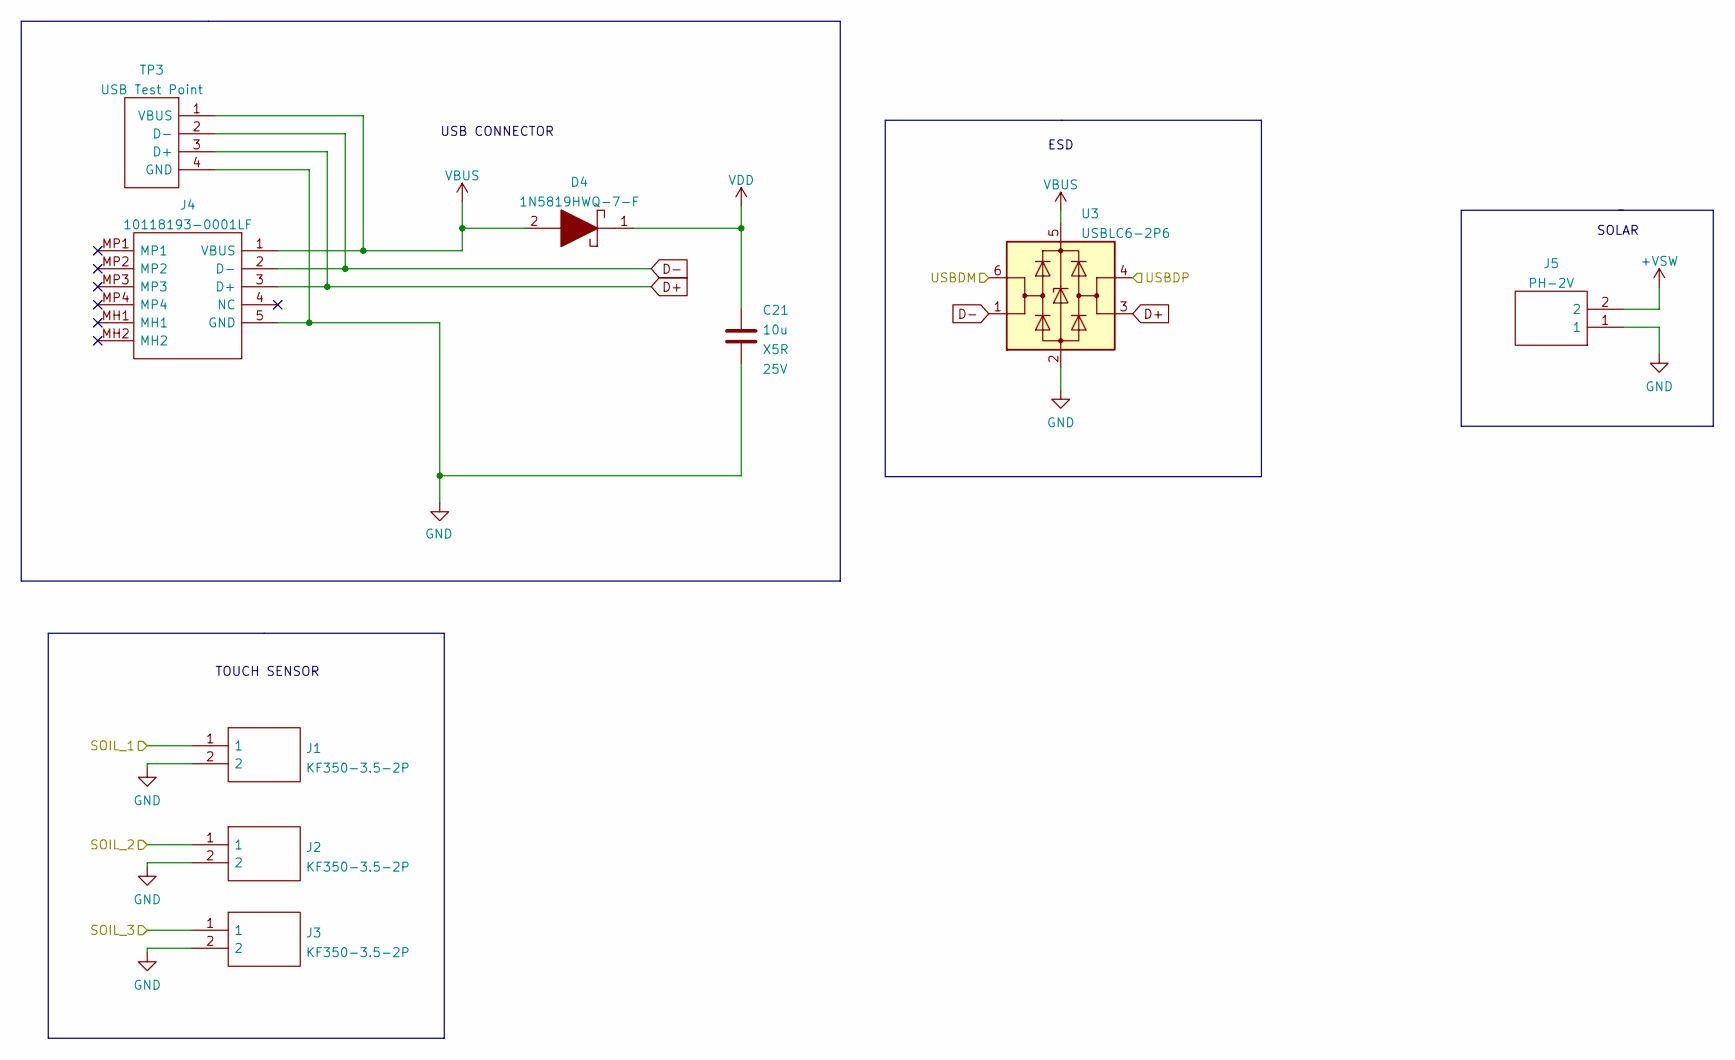
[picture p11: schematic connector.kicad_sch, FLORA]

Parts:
C21: 10u; C_0805_2012Metric; Voltage 25V; LCSC C15850
D4: 1N5819HWQ-7-F; SOD3716X145N; Manufacturer_Part_Number 1N5819HWQ-7-F; Mouser Part Number 621-1N5819HWQ-7-F
J1, J2, J3: KF350-3.5-2P; KF350352P; Manufacturer_Part_Number KF350-3.5-2P; LCSC C474892
J4: 10118193-0001LF; 101181930001LF; Manufacturer_Part_Number 10118193-0001LF; Mouser Part Number 649-10118193-0001LF
J5: PH-2V; SHDR2W52P0X200_1X2_600X460X630P; Manufacturer_Part_Number PH-2AK; LCSC C146082
TP3: USB Test Point; USB_TestPoint
U3: USBLC6-2P6; SOT-666; LCSC C2827693

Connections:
+VSW: J5.2; also elsewhere on the board
/Connector/USBDM: U3.6 (I/O1); also elsewhere on the board
/Connector/USBDP: U3.4 (I/O2); also elsewhere on the board
D+: J4.3 (D+), TP3.3 (D+), U3.3 (I/O2)
D-: J4.2 (D-), TP3.2 (D-), U3.1 (I/O1)
GND: C21.2, J1.2, J2.2, J3.2, J4.5 (GND), J5.1, TP3.4 (GND), U3.2 (GND); also elsewhere on the board
GPIO12: J2.1; also elsewhere on the board
GPIO13: J3.1; also elsewhere on the board
GPIO14: J1.1; also elsewhere on the board
VBUS: D4.2, J4.1 (VBUS), TP3.1 (VBUS), U3.5 (VBUS)
VDD: C21.1, D4.1; also elsewhere on the board

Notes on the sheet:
SOLAR
USB CONNECTOR
ESD
TOUCH SENSOR

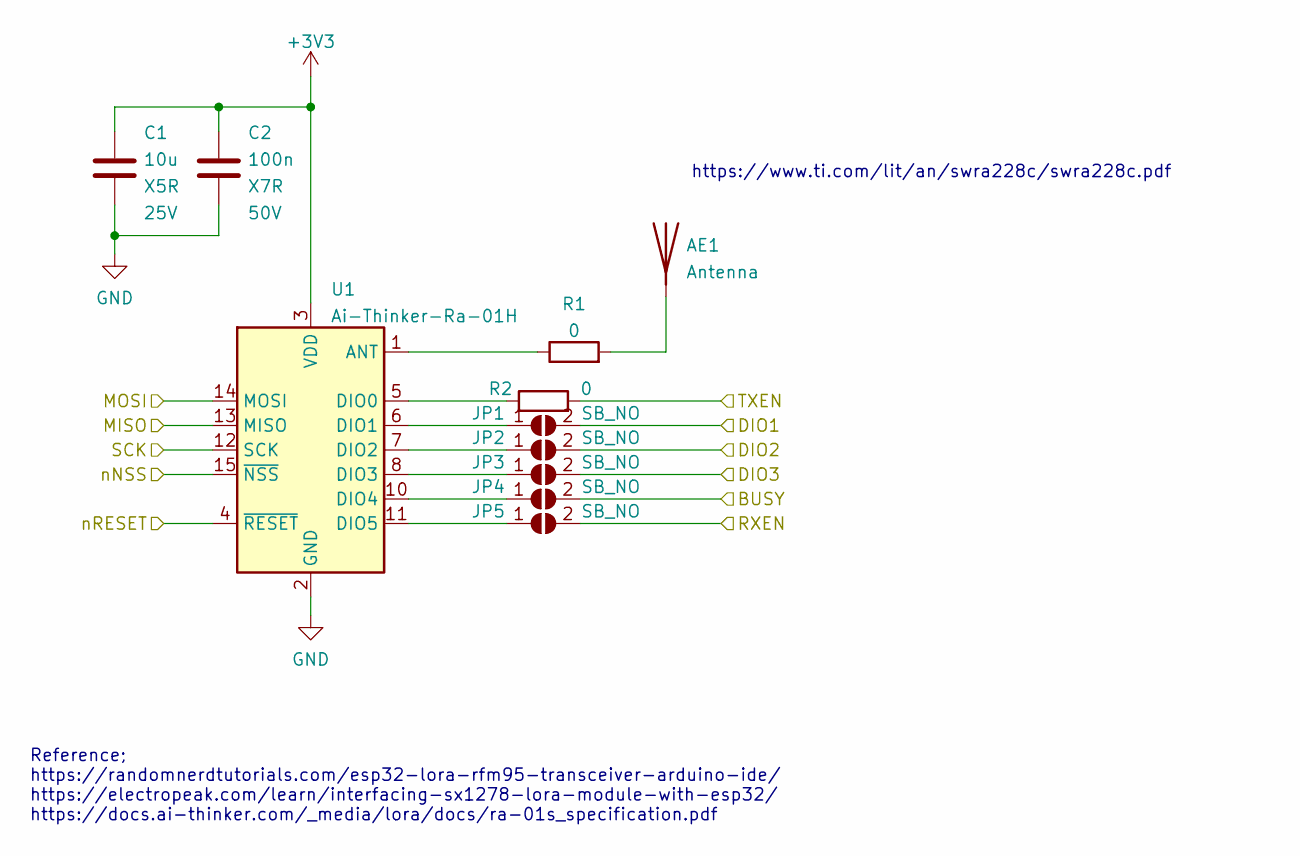
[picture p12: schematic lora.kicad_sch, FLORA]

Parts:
AE1: Antenna; Texas_SWRA416_868MHz_915MHz
C1: 10u; C_0805_2012Metric; Voltage 25V; LCSC C15850
C2: 100n; C_0402_1005Metric; Voltage 50V; LCSC C307331
JP1, JP2, JP3, JP4, JP5: SB_NO; SolderJumper-2_P1.3mm_Open_TrianglePad1.0x1.5mm
R1, R2: 0; R_0805_2012Metric_Pad1.20x1.40mm_HandSolder; LCSC C17477
U1: Ai-Thinker-Ra-01H; Ai-Thinker-Ra-01-LoRa; LCSC C503593

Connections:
+3V3: C1.1, C2.1, U1.3 (VDD); also elsewhere on the board
GND: C1.2, C2.2, U1.2 (GND), U1.9 (GND), U1.16 (GND); also elsewhere on the board
GPIO2: R2.2; also elsewhere on the board
GPIO5: U1.15 (~NSS); also elsewhere on the board
GPIO14: U1.4 (~RESET); also elsewhere on the board
GPIO18: U1.12 (SCK); also elsewhere on the board
GPIO19: U1.13 (MISO); also elsewhere on the board
GPIO21: JP4.2 (B); also elsewhere on the board
GPIO22: JP5.2 (B); also elsewhere on the board
GPIO23: U1.14 (MOSI); also elsewhere on the board
GPIO25: JP1.2 (B); also elsewhere on the board
GPIO26: JP2.2 (B); also elsewhere on the board
GPIO27: JP3.2 (B); also elsewhere on the board
unnamed: AE1.1 (A), R1.2
unnamed: JP1.1 (A), U1.6 (DIO1)
unnamed: JP2.1 (A), U1.7 (DIO2)
unnamed: JP3.1 (A), U1.8 (DIO3)
unnamed: JP4.1 (A), U1.10 (DIO4)
unnamed: JP5.1 (A), U1.11 (DIO5)
unnamed: R1.1, U1.1 (ANT)
unnamed: R2.1, U1.5 (DIO0)

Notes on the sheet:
https://www.ti.com/lit/an/swra228c/swra228c.pdf
Reference; https://randomnerdtutorials.com/esp32-lora-rfm95-transceiver-arduino-ide/ https://electropeak.com/learn/interfacing-sx1278-lora-module-with-esp32/ https://docs.ai-thinker.com/_media/lora/docs/ra-01s_specification.pdf

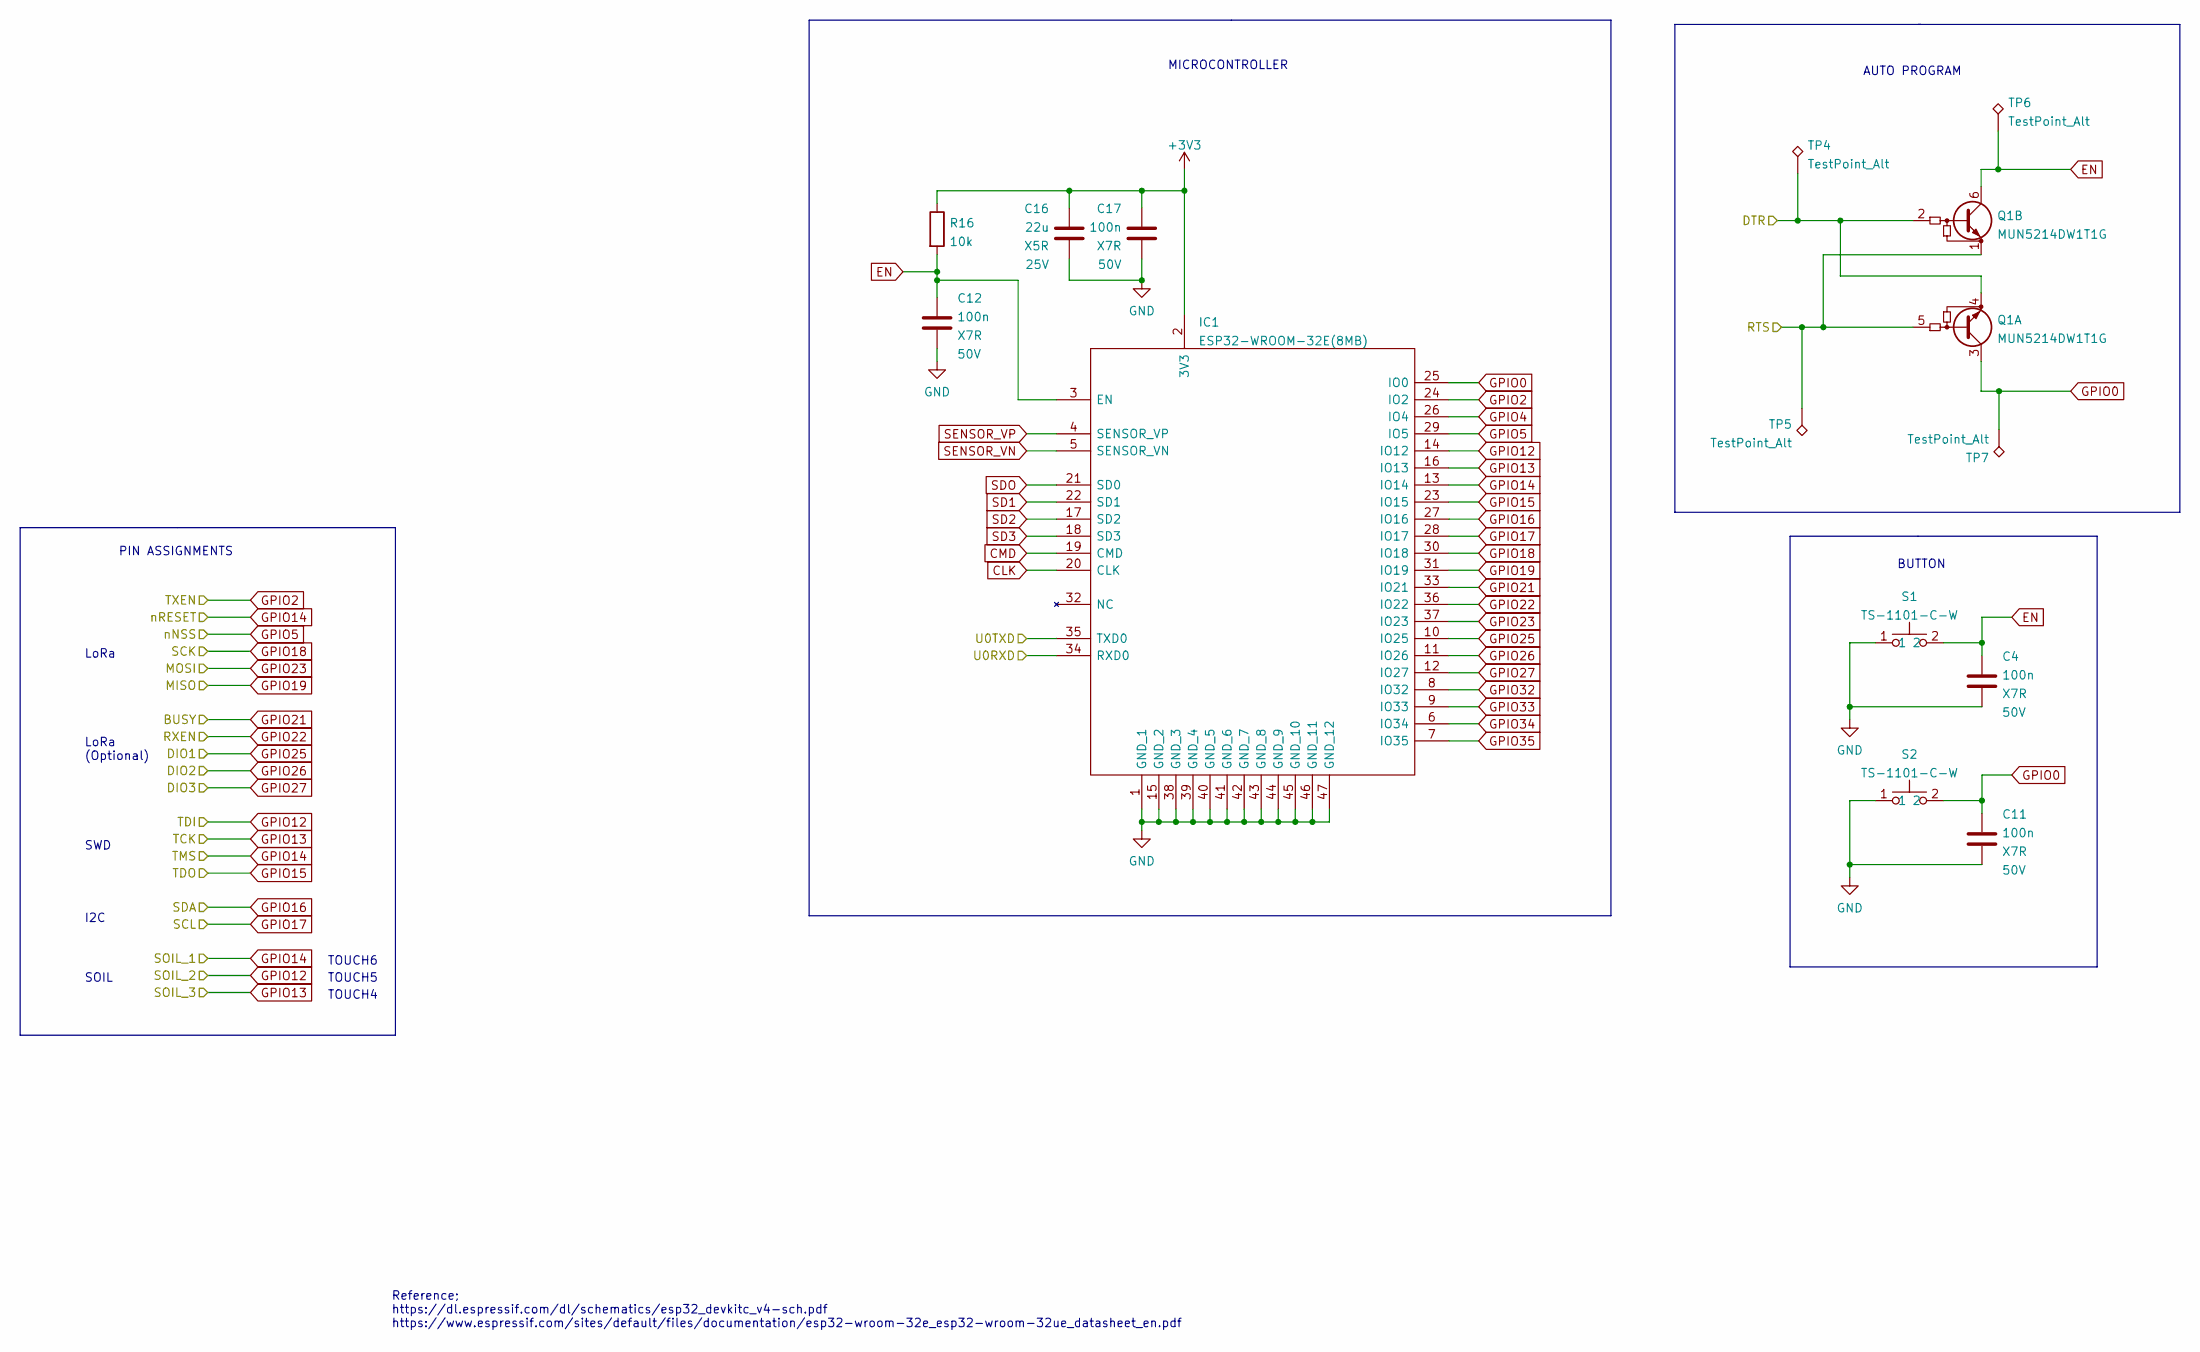
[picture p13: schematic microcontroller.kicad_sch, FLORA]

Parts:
C4, C11, C12, C17: 100n; C_0402_1005Metric; Voltage 50V; LCSC C307331
C16: 22u; C_0805_2012Metric; Voltage 25V; LCSC C602037
IC1: ESP32-WROOM-32E(8MB); ESP32WROOM32E8MB; Manufacturer_Part_Number ESP32-WROOM-32E (8MB); Mouser Part Number 356-ESP32WRM32E164PH
Q1: MUN5214DW1T1G; SOT-363_SC-70-6; LCSC C94403
R16: 10k; R_0402_1005Metric; LCSC C25744
S1, S2: TS-1101-C-W; TS1101CW; Manufacturer_Part_Number TS-1101-C-W; LCSC C318938
TP4, TP5, TP6, TP7: TestPoint_Alt; TestPoint_Pad_1.0x1.0mm

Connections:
+3V3: C16.1, C17.1, IC1.2 (3V3), R16.1; also elsewhere on the board
/Microcontroller/DTR: Q1.2 (B2), Q1.4 (E1), TP4.1; also elsewhere on the board
/Microcontroller/RTS: Q1.1 (E2), Q1.5 (B1), TP5.1; also elsewhere on the board
/Microcontroller/U0RXD: IC1.34 (RXD0); also elsewhere on the board
/Microcontroller/U0TXD: IC1.35 (TXD0); also elsewhere on the board
CLK: IC1.20 (CLK)
CMD: IC1.19 (CMD)
EN: C4.2, C12.1, IC1.3 (EN), Q1.6 (C2), R16.2, S1.2, TP6.1
GND: C4.1, C11.1, C12.2, C16.2, C17.2, IC1.1 (GND_1), IC1.15 (GND_2), IC1.38 (GND_3), IC1.39 (GND_4), IC1.40 (GND_5), IC1.41 (GND_6), IC1.42 (GND_7), IC1.43 (GND_8), IC1.44 (GND_9), IC1.45 (GND_10), IC1.46 (GND_11), IC1.47 (GND_12), S1.1, S2.1; also elsewhere on the board
GPIO0: C11.2, IC1.25 (IO0), Q1.3 (C1), S2.2, TP7.1
GPIO2: IC1.24 (IO2); also elsewhere on the board
GPIO4: IC1.26 (IO4)
GPIO5: IC1.29 (IO5); also elsewhere on the board
GPIO12: IC1.14 (IO12); also elsewhere on the board
GPIO13: IC1.16 (IO13); also elsewhere on the board
GPIO14: IC1.13 (IO14); also elsewhere on the board
GPIO15: IC1.23 (IO15)
GPIO16: IC1.27 (IO16); also elsewhere on the board
GPIO17: IC1.28 (IO17); also elsewhere on the board
GPIO18: IC1.30 (IO18); also elsewhere on the board
GPIO19: IC1.31 (IO19); also elsewhere on the board
GPIO21: IC1.33 (IO21); also elsewhere on the board
GPIO22: IC1.36 (IO22); also elsewhere on the board
GPIO23: IC1.37 (IO23); also elsewhere on the board
GPIO25: IC1.10 (IO25); also elsewhere on the board
GPIO26: IC1.11 (IO26); also elsewhere on the board
GPIO27: IC1.12 (IO27); also elsewhere on the board
GPIO32: IC1.8 (IO32)
GPIO33: IC1.9 (IO33)
GPIO34: IC1.6 (IO34)
GPIO35: IC1.7 (IO35)
SD1: IC1.22 (SD1)
SD2: IC1.17 (SD2)
SD3: IC1.18 (SD3)
SDO: IC1.21 (SD0)
SENSOR_VN: IC1.5 (SENSOR_VN)
SENSOR_VP: IC1.4 (SENSOR_VP)

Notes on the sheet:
AUTO PROGRAM
PIN ASSIGNMENTS
BUTTON
MICROCONTROLLER
SWD
LoRa (Optional)
SOIL
Reference; https://dl.espressif.com/dl/schematics/esp32_devkitc_v4-sch.pdf https://www.espressif.com/sites/default/files/documentation/esp32-wroom-32e_esp32-wroom-32ue_datasheet_en.pdf
LoRa
TOUCH6
TOUCH4
I2C
TOUCH5

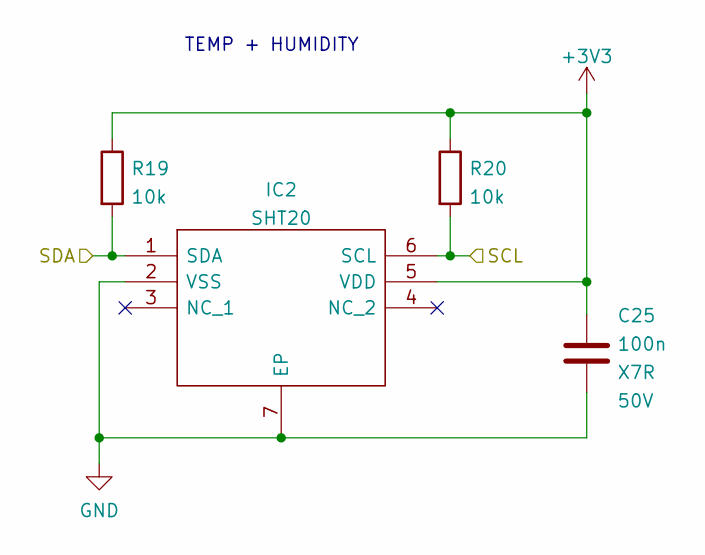
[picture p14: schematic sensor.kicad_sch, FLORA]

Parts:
C25: 100n; C_0402_1005Metric; Voltage 50V; LCSC C307331
IC2: SHT20; SON100P300X300X110-7N; Mouser Part Number 403-SHT20
R19, R20: 10k; R_0402_1005Metric; LCSC C25744

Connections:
+3V3: C25.1, IC2.5 (VDD), R19.1, R20.1; also elsewhere on the board
GND: C25.2, IC2.2 (VSS), IC2.7 (EP); also elsewhere on the board
GPIO16: IC2.1 (SDA), R19.2; also elsewhere on the board
GPIO17: IC2.6 (SCL), R20.2; also elsewhere on the board

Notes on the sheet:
TEMP + HUMIDITY

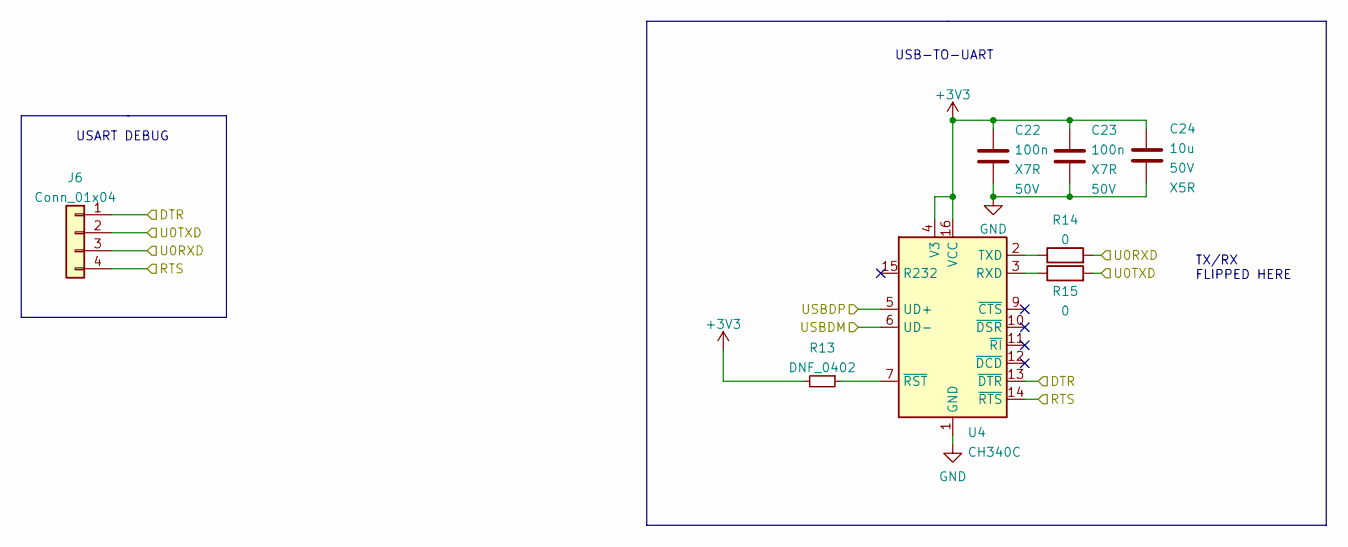
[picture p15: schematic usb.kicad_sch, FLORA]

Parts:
C22, C23: 100n; C_0402_1005Metric; Voltage 50V; LCSC C307331
C24: 10u; C_0805_2012Metric; Rated Voltage 50V; LCSC C440198
J6: Conn_01x04; PinHeader_1x04_P1.27mm_Vertical
R13: DNF_0402; R_0402_1005Metric
R14, R15: 0; R_0805_2012Metric_Pad1.20x1.40mm_HandSolder; LCSC C17477
U4: CH340C; SOIC-16_3.9x9.9mm_P1.27mm; LCSC C84681

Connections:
+3V3: C22.1, C23.1, C24.1, R13.2, U4.4 (V3), U4.16 (VCC); also elsewhere on the board
/Connector/USBDM: U4.6 (UD-); also elsewhere on the board
/Connector/USBDP: U4.5 (UD+); also elsewhere on the board
/Microcontroller/DTR: J6.1, U4.13 (~DTR); also elsewhere on the board
/Microcontroller/RTS: J6.4, U4.14 (~RTS); also elsewhere on the board
/Microcontroller/U0RXD: J6.3, R14.2; also elsewhere on the board
/Microcontroller/U0TXD: J6.2, R15.2; also elsewhere on the board
GND: C22.2, C23.2, C24.2, U4.1 (GND); also elsewhere on the board
unnamed: R13.1, U4.7 (~RST)
unnamed: R14.1, U4.2 (TXD)
unnamed: R15.1, U4.3 (RXD)

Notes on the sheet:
USB-TO-UART
USART DEBUG
TX/RX FLIPPED HERE

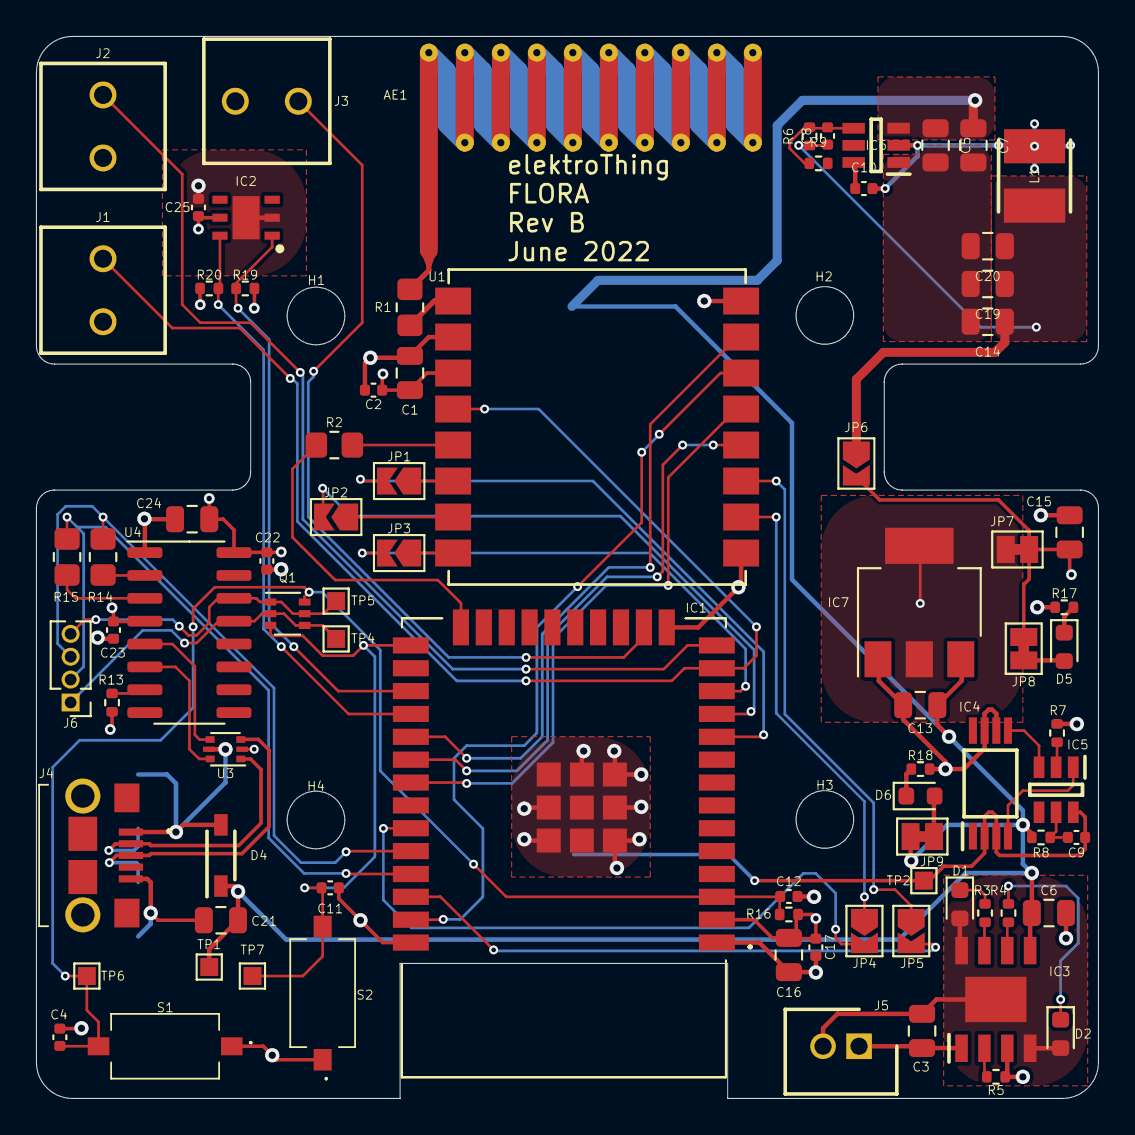
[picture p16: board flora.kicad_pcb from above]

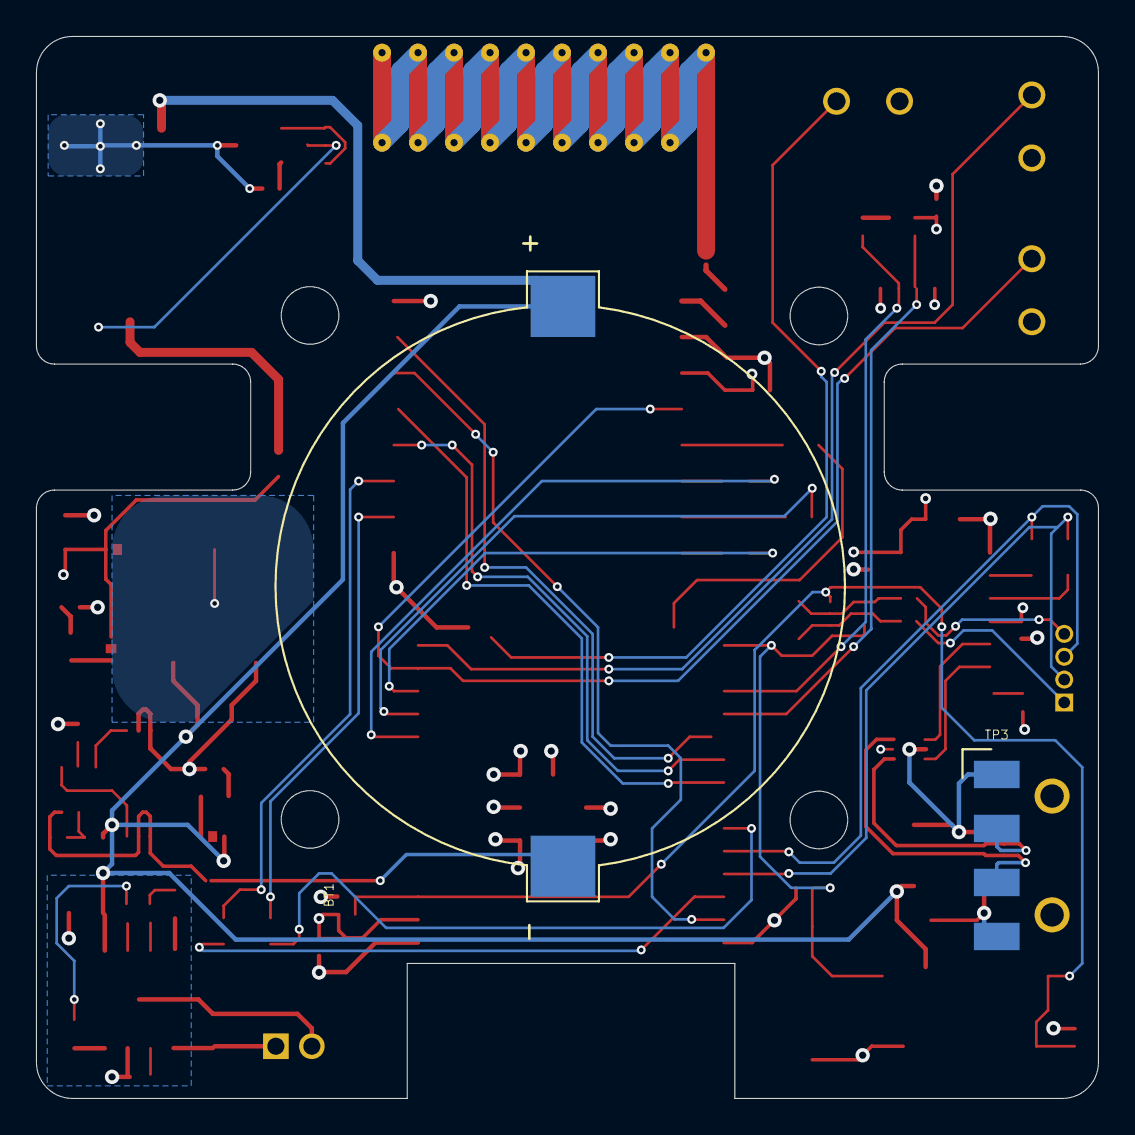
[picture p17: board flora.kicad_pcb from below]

Board: 4 copper layers, 59.0 x 59.0 mm, 88 parts (2 on the bottom side), 60 nets.

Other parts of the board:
H1, H2, H3, H4: MountingHole; MountingHole_3.2mm_M3_Small

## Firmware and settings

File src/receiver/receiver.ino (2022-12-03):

/*
DOIT ESP32 DEVKIT V1
*/

#include <esp_now.h>
#include <WiFi.h>
#include "ESPAsyncWebServer.h"
#include <Arduino_JSON.h>
#include "ThingSpeak.h"
WiFiClient  client;

// Sleep for 10 minutes after data point
int time_in_us = 25*60*1000000;
unsigned long myChannelNumber = 1756801;
const char * myWriteAPIKey = "46LUWZJQL7LBCMVN";
// Replace with your network credentials (STATION)
const char* ssid = "VM5191158_EXT";
const char* password = "kgLpwnrX3jrr";

// Structure example to receive data
// Must match the sender structure
typedef struct struct_message {
  int id;
  float temp;
  float hum;
  float moist_1;
  float moist_2;
  unsigned int readingId;
} struct_message;
bool newData = false;
struct_message incomingReadings;

JSONVar board;

//AsyncWebServer server(80);
AsyncEventSource events("/events");

// callback function that will be executed when data is received
void OnDataRecv(const uint8_t * mac_addr, const uint8_t *incomingData, int len) {
  // Copies the sender mac address to a string
  char macStr[18];
  Serial.print("Packet received from: ");
  snprintf(macStr, sizeof(macStr), "%02x:%02x:%02x:%02x:%02x:%02x",
           mac_addr[0], mac_addr[1], mac_addr[2], mac_addr[3], mac_addr[4], mac_addr[5]);
  Serial.println(macStr);
  memcpy(&incomingReadings, incomingData, sizeof(incomingReadings));

  board["id"] = incomingReadings.id;
  board["temperature"] = incomingReadings.temp;
  board["humidity"] = incomingReadings.hum;
  board["moist 1"] = incomingReadings.moist_1;
  board["moist 2"] = incomingReadings.moist_2;
  board["readingId"] = String(incomingReadings.readingId);
  String jsonString = JSON.stringify(board);
  events.send(jsonString.c_str(), "new_readings", millis());

  Serial.printf("Board ID %u: %u bytes\n", incomingReadings.id, len);
  Serial.printf("t value: %4.2f \n", incomingReadings.temp);
  Serial.printf("h value: %4.2f \n", incomingReadings.hum);
  Serial.printf("m1 value: %4.2f \n", incomingReadings.moist_1);
  Serial.printf("m2 value: %4.2f \n", incomingReadings.moist_2);
  Serial.printf("readingID value: %d \n", incomingReadings.readingId);
  Serial.println();

  newData = true;
}

//const char index_html[] PROGMEM = R"rawliteral(
//<!DOCTYPE HTML><html>
//<head>
//  <title>ESP-NOW DASHBOARD</title>
//  <meta name="viewport" content="width=device-width, initial-scale=1">
//  <link rel="stylesheet" href="https://use.fontawesome.com/releases/v5.7.2/css/all.css" integrity="sha384-fnmOCqbTlWIlj8LyTjo7mOUStjsKC4pOpQbqyi7RrhN7udi9RwhKkMHpvLbHG9Sr" crossorigin="anonymous">
//  <link rel="icon" href="data:,">
//  <style>
//    html {font-family: Arial; display: inline-block; text-align: center;}
//    p {  font-size: 1.2rem;}
//    body {  margin: 0;}
//    .topnav { overflow: hidden; background-color: #2f4468; color: white; font-size: 1.7rem; }
//    .content { padding: 20px; }
//    .card { background-color: white; box-shadow: 2px 2px 12px 1px rgba(140,140,140,.5); }
//    .cards { max-width: 700px; margin: 0 auto; display: grid; grid-gap: 2rem; grid-template-columns: repeat(auto-fit, minmax(300px, 1fr)); }
//    .reading { font-size: 2.8rem; }
//    .packet { color: #bebebe; }
//    .card.temperature { color: #fd7e14; }
//    .card.humidity { color: #1b78e2; }
//  </style>
//</head>
//<body>
//  <div class="topnav">
//    <h3>ESP-NOW DASHBOARD</h3>
//  </div>
//  <div class="content">
//    <div class="cards">
//      <div class="card temperature">
//        <h4><i class="fas fa-thermometer-half"></i> BOARD #1 - TEMPERATURE</h4><p><span class="reading"><span id="t1"></span> &deg;C</span></p><p class="packet">Reading ID: <span id="rt1"></span></p>
//      </div>
//      <div class="card humidity">
//        <h4><i class="fas fa-tint"></i> BOARD #1 - HUMIDITY</h4><p><span class="reading"><span id="h1"></span> &percnt;</span></p><p class="packet">Reading ID: <span id="rh1"></span></p>
//      </div>
//      <div class="card temperature">
//        <h4><i class="fas fa-thermometer-half"></i> BOARD #2 - TEMPERATURE</h4><p><span class="reading"><span id="t2"></span> &deg;C</span></p><p class="packet">Reading ID: <span id="rt2"></span></p>
//      </div>
//      <div class="card humidity">
//        <h4><i class="fas fa-tint"></i> BOARD #2 - HUMIDITY</h4><p><span class="reading"><span id="h2"></span> &percnt;</span></p><p class="packet">Reading ID: <span id="rh2"></span></p>
//      </div>
//    </div>
//  </div>
//<script>
//if (!!window.EventSource) {
// var source = new EventSource('/events');
//
// source.addEventListener('open', function(e) {
//  console.log("Events Connected");
// }, false);
// source.addEventListener('error', function(e) {
//  if (e.target.readyState != EventSource.OPEN) {
//    console.log("Events Disconnected");
//  }
// }, false);
//
// source.addEventListener('message', function(e) {
//  console.log("message", e.data);
// }, false);
//
// source.addEventListener('new_readings', function(e) {
//  console.log("new_readings", e.data);
//  var obj = JSON.parse(e.data);
//  document.getElementById("t"+obj.id).innerHTML = obj.temperature.toFixed(2);
//  document.getElementById("h"+obj.id).innerHTML = obj.humidity.toFixed(2);
//  document.getElementById("rt"+obj.id).innerHTML = obj.readingId;
//  document.getElementById("rh"+obj.id).innerHTML = obj.readingId;
// }, false);
//}
//</script>
//</body>
//</html>)rawliteral";

void setup() {
  // Initialize Serial Monitor
  Serial.begin(115200);
  esp_sleep_enable_timer_wakeup(time_in_us);
  delay(500);
  // Set the device as a Station and Soft Access Point simultaneously
  WiFi.mode(WIFI_AP_STA);
  delay(500);
  // Set device as a Wi-Fi Station
  WiFi.begin(ssid, password);
  delay(500);
  int tryCounter = 0;
  while (WiFi.status() != WL_CONNECTED) {
    if (tryCounter==10)
    {
      Serial.println("Restarting...");
      ESP.restart();
    }
    delay(1000);
    Serial.println("Setting as a Wi-Fi Station..");
    tryCounter++;
  }
  Serial.print("MAC Address:  ");
  Serial.println(WiFi.macAddress());
  Serial.print("Station IP Address: ");
  Serial.println(WiFi.localIP());
  Serial.print("Wi-Fi Channel: ");
  Serial.println(WiFi.channel());

  // Init ESP-NOW
  if (esp_now_init() != ESP_OK) {
    Serial.println("Error initializing ESP-NOW");
    return;
  }
  ThingSpeak.begin(client);  // Initialize ThingSpeak
  // Once ESPNow is successfully Init, we will register for recv CB to
  // get recv packer info
  esp_now_register_recv_cb(OnDataRecv);

//  server.on("/", HTTP_GET, [](AsyncWebServerRequest * request) {
//    request->send_P(200, "text/html", index_html);
//  });

  events.onConnect([](AsyncEventSourceClient * client) {
    if (client->lastId()) {
      Serial.printf("Client reconnected! Last message ID that it got is: %u\n", client->lastId());
    }
    // send event with message "hello!", id current millis
    // and set reconnect delay to 1 second
    client->send("hello!", NULL, millis(), 10000);
  });
//  server.addHandler(&events);
//  server.begin();
  Serial.println("Listening...");
}

void loop() {
//  static unsigned long lastEventTime = millis();
//  static const unsigned long EVENT_INTERVAL_MS = 5000;
//  if ((millis() - lastEventTime) > EVENT_INTERVAL_MS) {
    events.send("ping", NULL, millis());
//    lastEventTime = millis();
    if (newData)
    {
      ThingSpeak.setField(1, incomingReadings.temp);
      ThingSpeak.setField(2, incomingReadings.hum);
      ThingSpeak.setField(3, incomingReadings.moist_1);
      ThingSpeak.setField(4, incomingReadings.moist_2);
      int x = ThingSpeak.writeFields(myChannelNumber, myWriteAPIKey);
      newData = false;
      Serial.println("Going to sleep now");
      delay(1000);
      Serial.flush(); 
      esp_deep_sleep_start();
    }
    delay(500);
//  }

}

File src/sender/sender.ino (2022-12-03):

#define uS_TO_S_FACTOR 1000000ULL  /* Conversion factor for micro seconds to seconds */
#define TIME_TO_SLEEP  1800       /* Time ESP32 will go to sleep (in seconds) */

//24:4C:AB:16:91:50
/*
  Rui Santos
  Complete project details at https://RandomNerdTutorials.com/esp32-esp-now-wi-fi-web-server/

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
  The above copyright notice and this permission notice shall be included in all
  copies or substantial portions of the Software.
*/

#include <esp_now.h>
#include <esp_wifi.h>
#include <WiFi.h>
#include <Adafruit_Sensor.h>

// Set your Board ID (ESP32 Sender #1 = BOARD_ID 1, ESP32 Sender #2 = BOARD_ID 2, etc)
#define BOARD_ID 1

//MAC Address of the receiver
uint8_t broadcastAddress[] = {0x24, 0x4C, 0xAB, 0x16, 0x91, 0x50};

//Structure example to send data
//Must match the receiver structure
typedef struct struct_message {
  int id;
  float temp;
  float hum;
  float moist_1;
  float moist_2;
  int readingId;
} struct_message;

//Create a struct_message called myData
struct_message myData;

unsigned long previousMillis = 0;   // Stores last time temperature was published
const long interval = 10000;        // Interval at which to publish sensor readings

unsigned int readingId = 0;

// Insert your SSID
constexpr char WIFI_SSID[] = "VM5191158";

int32_t getWiFiChannel(const char *ssid) {
  if (int32_t n = WiFi.scanNetworks()) {
    for (uint8_t i = 0; i < n; i++) {
      if (!strcmp(ssid, WiFi.SSID(i).c_str())) {
        return WiFi.channel(i);
      }
    }
  }
  return 0;
}


// callback when data is sent
void OnDataSent(const uint8_t *mac_addr, esp_now_send_status_t status) {
  Serial.print("\r\nLast Packet Send Status:\t");
  Serial.println(status == ESP_NOW_SEND_SUCCESS ? "Delivery Success" : "Delivery Fail");
}
esp_now_peer_info_t peerInfo;
void setup() {
  //Init Serial Monitor
  Serial.begin(115200);

  // Set device as a Wi-Fi Station and set channel
  WiFi.mode(WIFI_STA);

  int32_t channel = getWiFiChannel(WIFI_SSID);

  WiFi.printDiag(Serial); // Uncomment to verify channel number before
  esp_wifi_set_promiscuous(true);
  esp_wifi_set_channel(channel, WIFI_SECOND_CHAN_NONE);
  esp_wifi_set_promiscuous(false);
  WiFi.printDiag(Serial); // Uncomment to verify channel change after

  //Init ESP-NOW
  if (esp_now_init() != ESP_OK) {
    Serial.println("Error initializing ESP-NOW");
    return;
  }

  // Once ESPNow is successfully Init, we will register for Send CB to
  // get the status of Trasnmitted packet
  esp_now_register_send_cb(OnDataSent);

  //Register peer

  memcpy(peerInfo.peer_addr, broadcastAddress, 6);
  peerInfo.encrypt = false;

  //Add peer
  if (esp_now_add_peer(&peerInfo) != ESP_OK) {
    Serial.println("Failed to add peer");
    return;
  }
  esp_sleep_enable_timer_wakeup(TIME_TO_SLEEP * uS_TO_S_FACTOR);

}

void loop() {

  // Save the last time a new reading was published
  //Set values to send
  myData.id = BOARD_ID;
  myData.temp = random(0,100);
  myData.hum = random(0,100);
  myData.readingId = readingId++;

  //Send message via ESP-NOW
  esp_err_t result = esp_now_send(broadcastAddress, (uint8_t *) &myData, sizeof(myData));
  if (result == ESP_OK) {
    Serial.println("Sent with success");

  }
  else {
    Serial.println("Error sending the data");
  }
  delay(5000);
  esp_deep_sleep_start();
}

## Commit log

2022-04-18 updated FLORA
    [battery.kicad_sch, connector.kicad_sch, flora.kicad_pcb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]
2022-04-27 Added comments to power
    [battery.kicad_sch]
2022-04-27 Removed header
    [battery.kicad_sch, connector.kicad_sch, flora.kicad_sch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]
2022-04-27 released Rev A
    [battery.kicad_sch, connector.kicad_sch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]
2022-06-05 added image
    [battery.kicad_sch, connector.kicad_sch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]
2022-07-01 commit backups
    [battery.kicad_sch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]
2022-07-01 Replaced SMPS
    [battery.kicad_sch, connector.kicad_sch, flora.kicad_pcb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]
